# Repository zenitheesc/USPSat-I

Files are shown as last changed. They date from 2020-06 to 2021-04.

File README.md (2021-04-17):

<h1 align="center" style="color:white; background-color:black">USP Sat-I</h1>
<h4 align="center">This is an Open Hardware and Software cubesat developed by Zenith EESC-USP for the Cubedesign 2019.</h4>

<p align="center">
	<a href="http://zenith.eesc.usp.br/">
    
    </a>
    <a href="https://eesc.usp.br/">
    
    </a>
    <a href="https://github.com/zenitheesc/USPSat-AE1/blob/main/LICENSE">
    
    </a>
    <a href="https://github.com/zenitheesc/USPSat-AE1/issues">
    
    </a>
    <a href="https://github.com/zenitheesc/USPSat-AE1/commits/main">
    
    </a>
    <a href="https://github.com/zenitheesc/USPSat-AE1/graphs/contributors">
    
    </a>
    <a href="https://github.com/zenitheesc/USPSat-AE1/commits/main">
    
    </a>
    <a href="https://github.com/zenitheesc/USPSat-AE1/issues">
    
    </a>
    <a href="https://github.com/zenitheesc/USPSat-AE1/pulls">
    
    </a>
</p>

This project was based on a distributed processing architecture and it uses microcontrollers with ARM architecture. The Embedded System is composed by six subsystems:

<a href="https://github.com/zenitheesc/USPSat-AE1/tree/master/M%C3%B3dulo_Ribatski%20v.1.0"><h2>1. Thermal management</h2></a>

<p align = "center">

</p>

This subsystem is primarily responsible for
the active thermal control of the batteries, as proposed by the competition,
in addition to supporting the deployment system of the nanosatellite antennas.

<a href="https://github.com/zenitheesc/USPSat-AE1/tree/master/Varela-Logical_EPS%20v.1.0"><h2>2. Logical EPS</h2></a>
<p align = "center">

</p>

Ensures the monitoring and control of EPS panel parameters,
that is, it performs the measurement of voltage and current levels at various points on the CubeSat;
monitors the temperature of the batteries and acts to keep it always positive, in addition to
carrying out the communication to other subsystems.

<a href="https://github.com/zenitheesc/USPSat-AE1/tree/master/London-Power_EPS%20v.1.1"><h2>3. Power EPS</h2></a>

<p align = "center">

</p>

Functioning as an extension of the previous subsystem, it performs conversions of battery voltage levels to the levels requested within the
hardware, making the necessary distribution, as well as controlling the loading of batteries through solar panels.

<a href="https://github.com/zenitheesc/USPSat-AE1/tree/master/Caurin_CDH%20v.1.0"><h2>4. Comanding and Data Handling</h2></a>

<p align = "center">

</p>

It concentrates one of the processing within CubeSat. It is responsible for managing the information
present in the prototype's internal network, by managing the information received and sent to the Control Base and control of the deployment of the antennas.

<a href="https://github.com/zenitheesc/USPSat-AE1/tree/master/Comin_CTR%20v.1.0"><h2>5. Computer Vision</h2></a>

<p align = "center">

</p>
This subsystem is responsible for image aquisition and on board image processing, for attitude determination using computer vision.

<a href="https://github.com/zenitheesc/USPSat-AE1/tree/master/Alves_ADC%20v.1.0"><h2> 6. Attitude Control </h2></a>

<p align = "center">

</p>

The entire stabilization and pointing system must be done necessary to fulfill the competition missions. For this, the reading is done necessary sensors, activating a reaction wheel, which, by means of the Law of
Conservation of Angular Momentum, manages to act in the attitude of the satellite.

## 7. Structures

<p align = "center">

</p>

Finally, we have the subsystem responsible for the physical integration of all
the subsystems described earlier. All manufacturing issues involving
the physical structure of USPSat is the responsibility of the structures subsystem. The
determination of the materials used, the choice of manufacturing processes and display of all components, aiming at a satisfactory performance in the
vibration, are the main focuses of this subsystem

## Official Documentation

Check out the official documentation [here](https://github.com/zenitheesc/USPSat-AE1/blob/master/USPSat_Report.pdf).

<p align = "center">



</p>

<p align="center">
    <a href="http://zenith.eesc.usp.br">
    
    </a> 
    <a href="https://www.facebook.com/zenitheesc">
    
    </a> 
    <a href="https://www.instagram.com/zenith_eesc/">
    
    </a>

</p>
<p align = "center">
<a href="zenith.eesc@gmail.com">zenith.eesc@gmail.com</a>
</p>

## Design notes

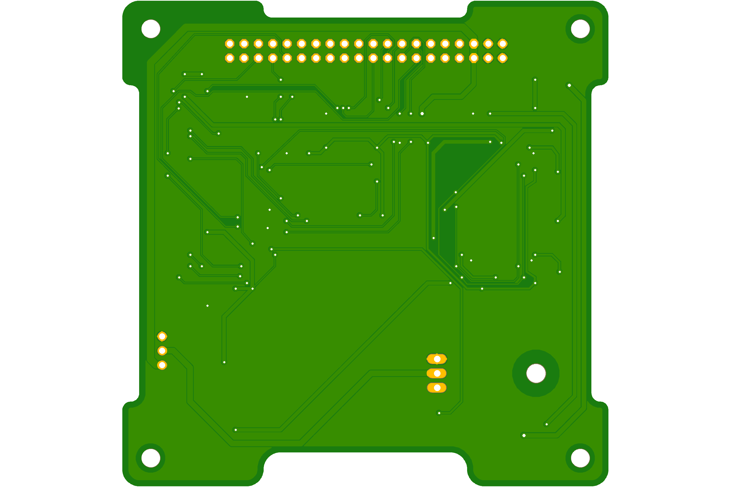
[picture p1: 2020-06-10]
Varela-Logical_EPS v.1.0/Images/Varela-Logical_EPS v.1.0 - Bottom.png

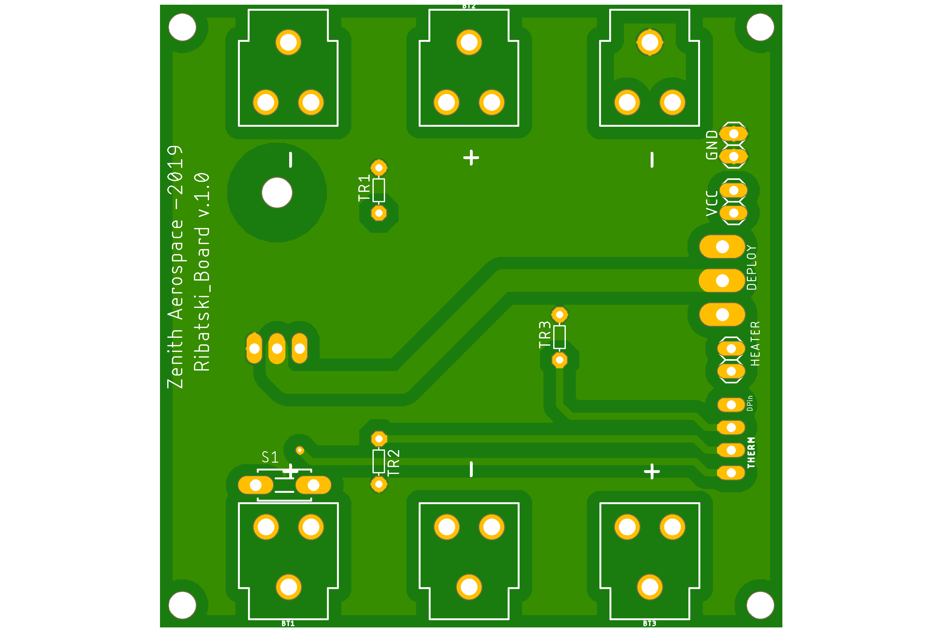
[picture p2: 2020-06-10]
Módulo_Ribatski v.1.0/Images/Módulo_Ribatski v.1.0 - Top.png

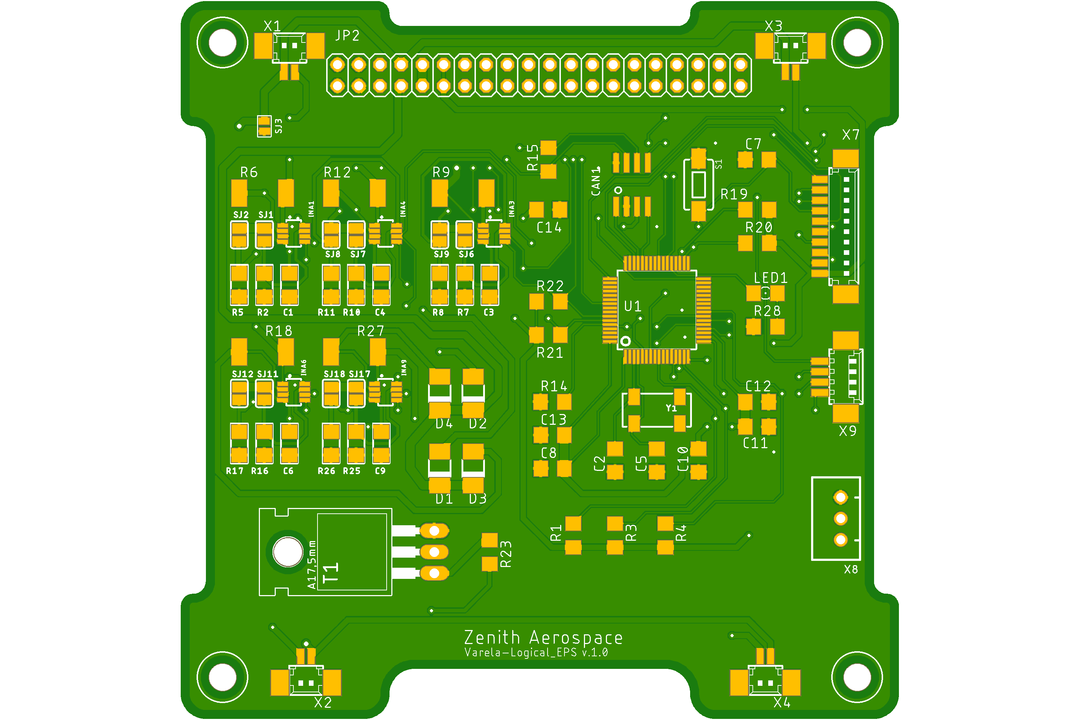
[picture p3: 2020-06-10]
Varela-Logical_EPS v.1.0/Images/Varela-Logical_EPS v.1.0 - Top.png

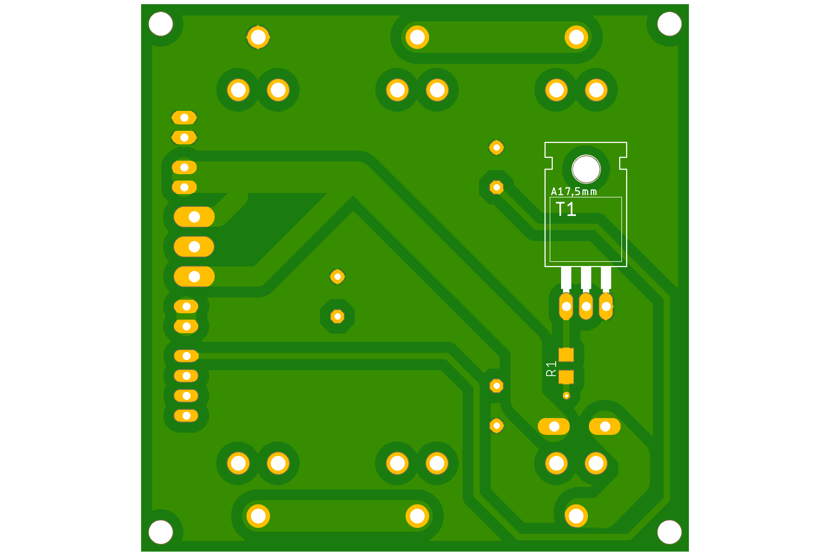
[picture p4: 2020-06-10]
Módulo_Ribatski v.1.0/Images/Módulo_Ribatski v.1.0 - Bottom.png

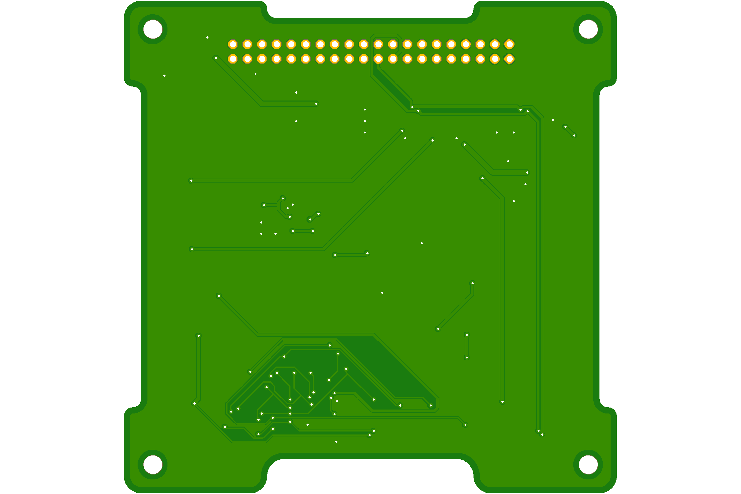
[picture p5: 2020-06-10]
London-Power_EPS v.1.1/Images/London-Power_EPS v.1.1 - Bottom.png

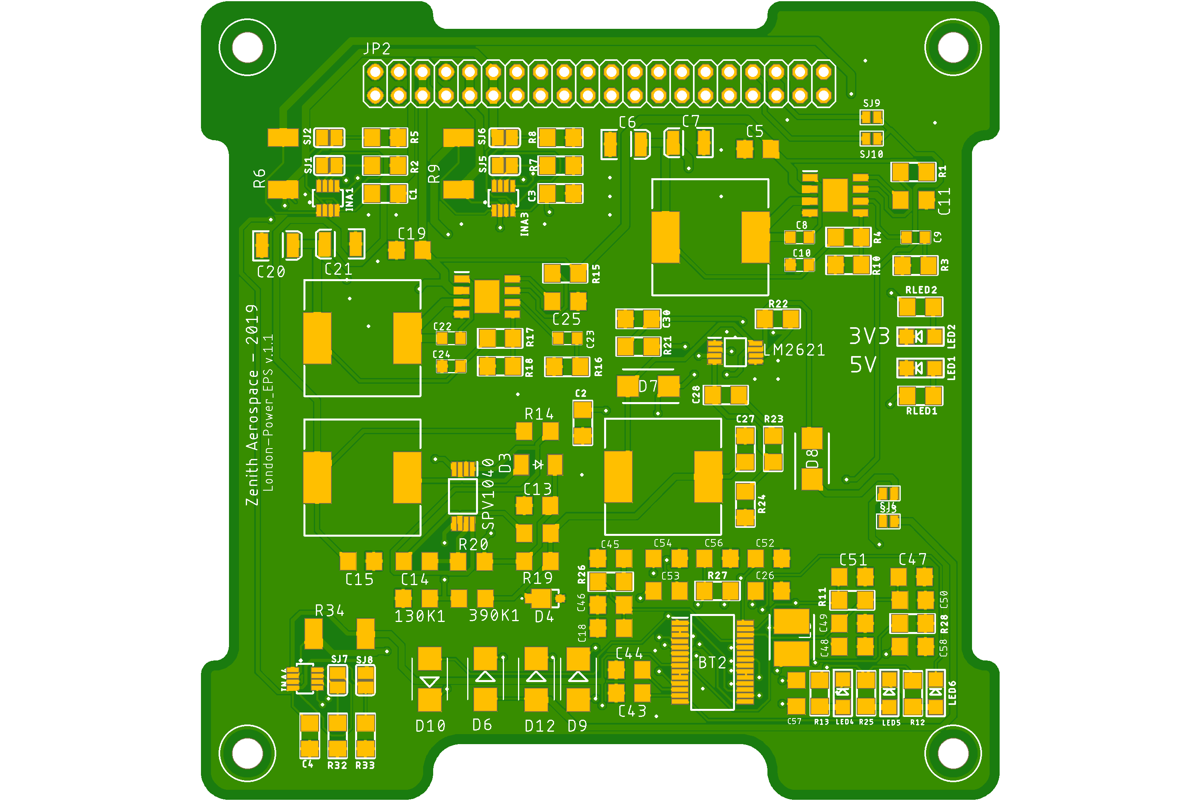
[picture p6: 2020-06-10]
London-Power_EPS v.1.1/Images/London-Power_EPS v.1.1 - Top.png

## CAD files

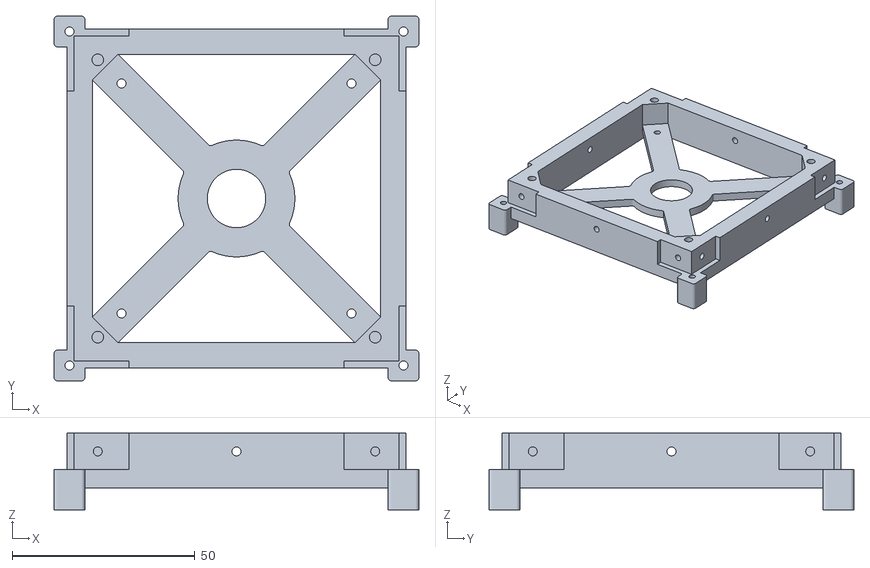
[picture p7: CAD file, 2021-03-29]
Estruturas/Base stl.stl
100.0 x 100.0 x 21.0

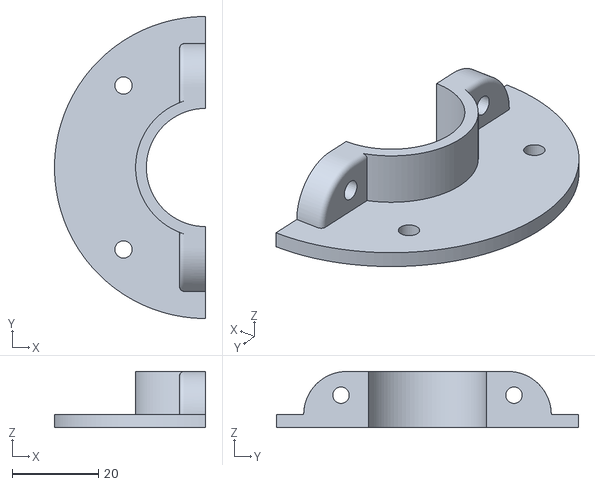
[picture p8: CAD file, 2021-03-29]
Estruturas/Espaçadores e Suporte motor/Suporte motor .stl
35.0 x 70.0 x 13.0

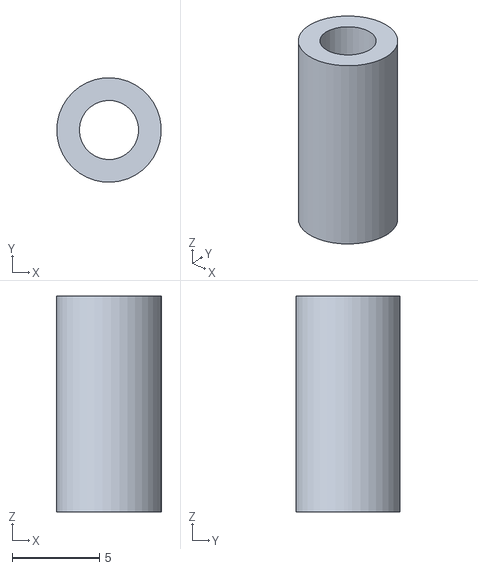
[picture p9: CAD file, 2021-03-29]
Estruturas/Espaçadores e Suporte motor/Espaçador_Placas.stl
6.00 x 6.00 x 12.4

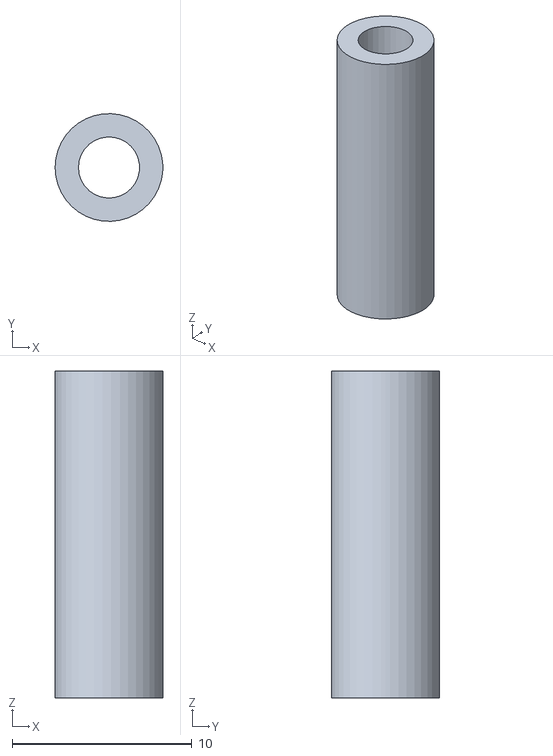
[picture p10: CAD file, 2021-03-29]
Estruturas/Espaçadores e Suporte motor/Espaçador_Base_Motor.stl
6.00 x 6.00 x 18.2

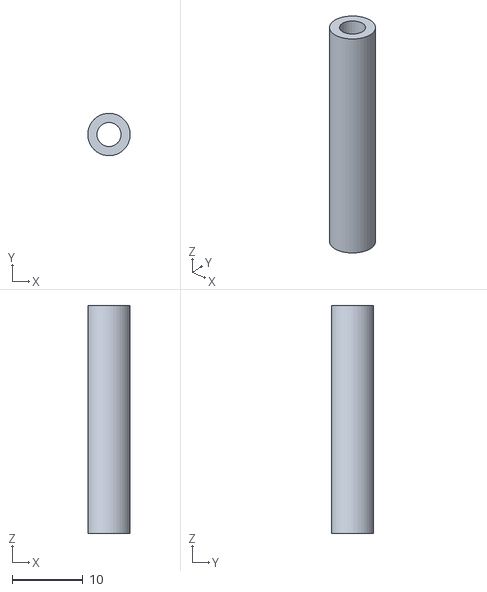
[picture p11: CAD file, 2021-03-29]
Estruturas/Espaçadores e Suporte motor/Espaçador_Meio.stl
6.00 x 6.00 x 32.2

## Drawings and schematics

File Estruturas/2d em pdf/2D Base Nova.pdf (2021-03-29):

B
C

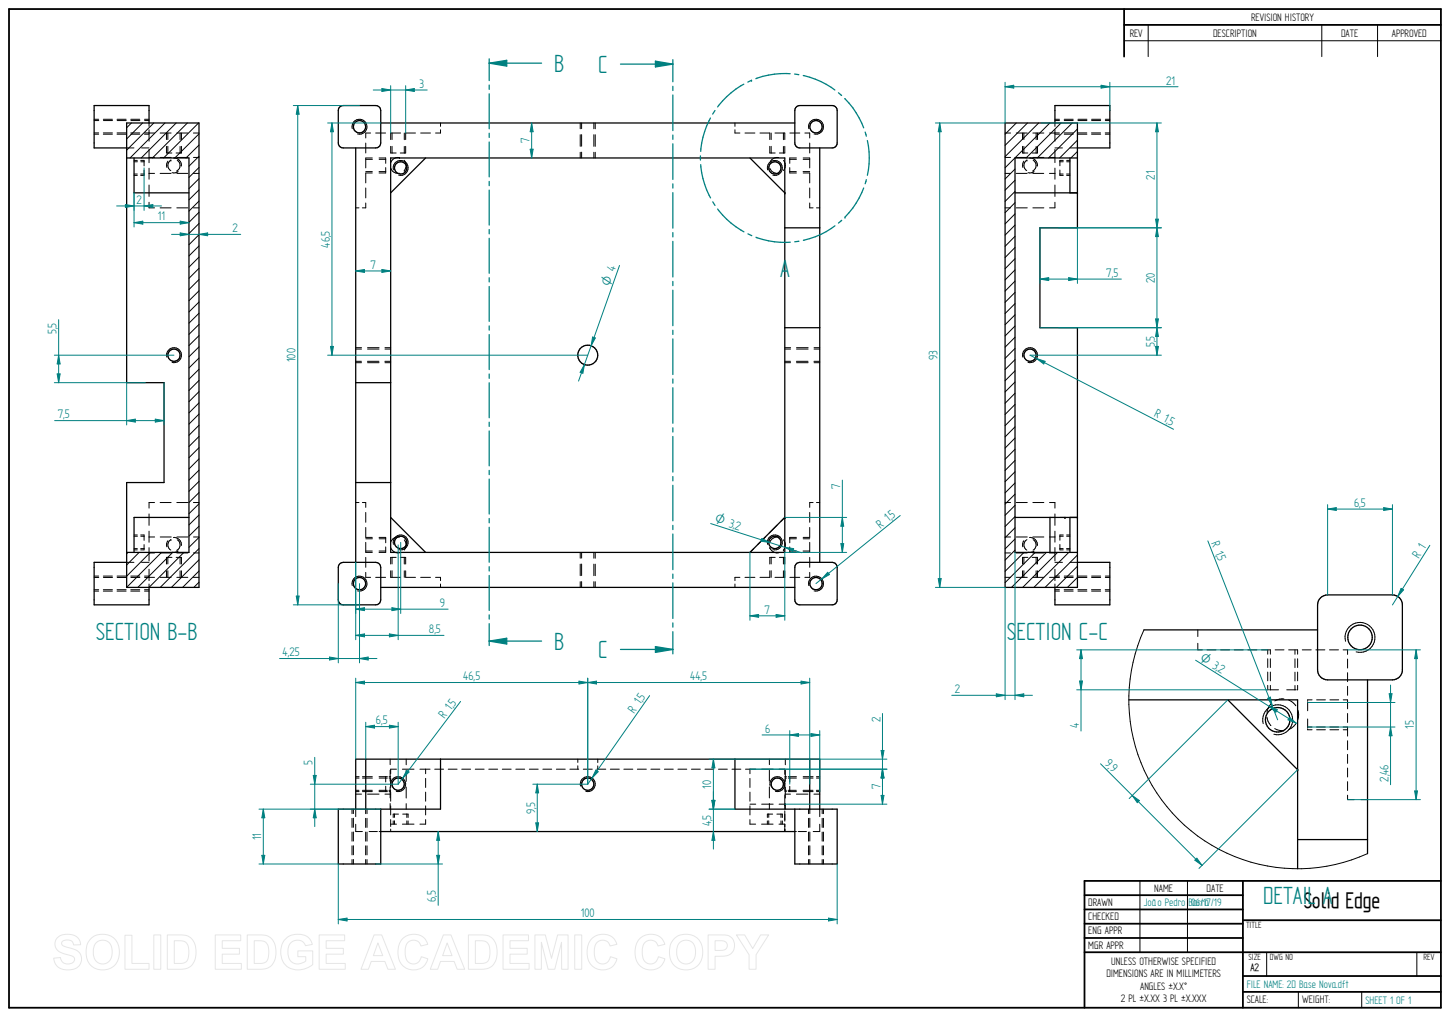
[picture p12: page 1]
TITLE; SCALE:; WEIGHT:; SHEET 1 OF 1; B SECTION B-B; SECTION C-C

REVISION HISTORY

REV | DESCRIPTION | DATE | APPROVED

NAME | DATE | DETAIL A Solid Edge

DRAWN | João Pedro Barra | 06/17/19

CHECKED
ENG APPR
MGR APPR
UNLESS OTHERWISE SPECIFIED DIMENSIONS ARE IN MILLIMETERS ANGLES ±X.X° 2 PL ±X.XX 3 PL ±X.XXX | SIZE A2 | DWG NO | REV

FILE NAME: 2D Base Nova.dft

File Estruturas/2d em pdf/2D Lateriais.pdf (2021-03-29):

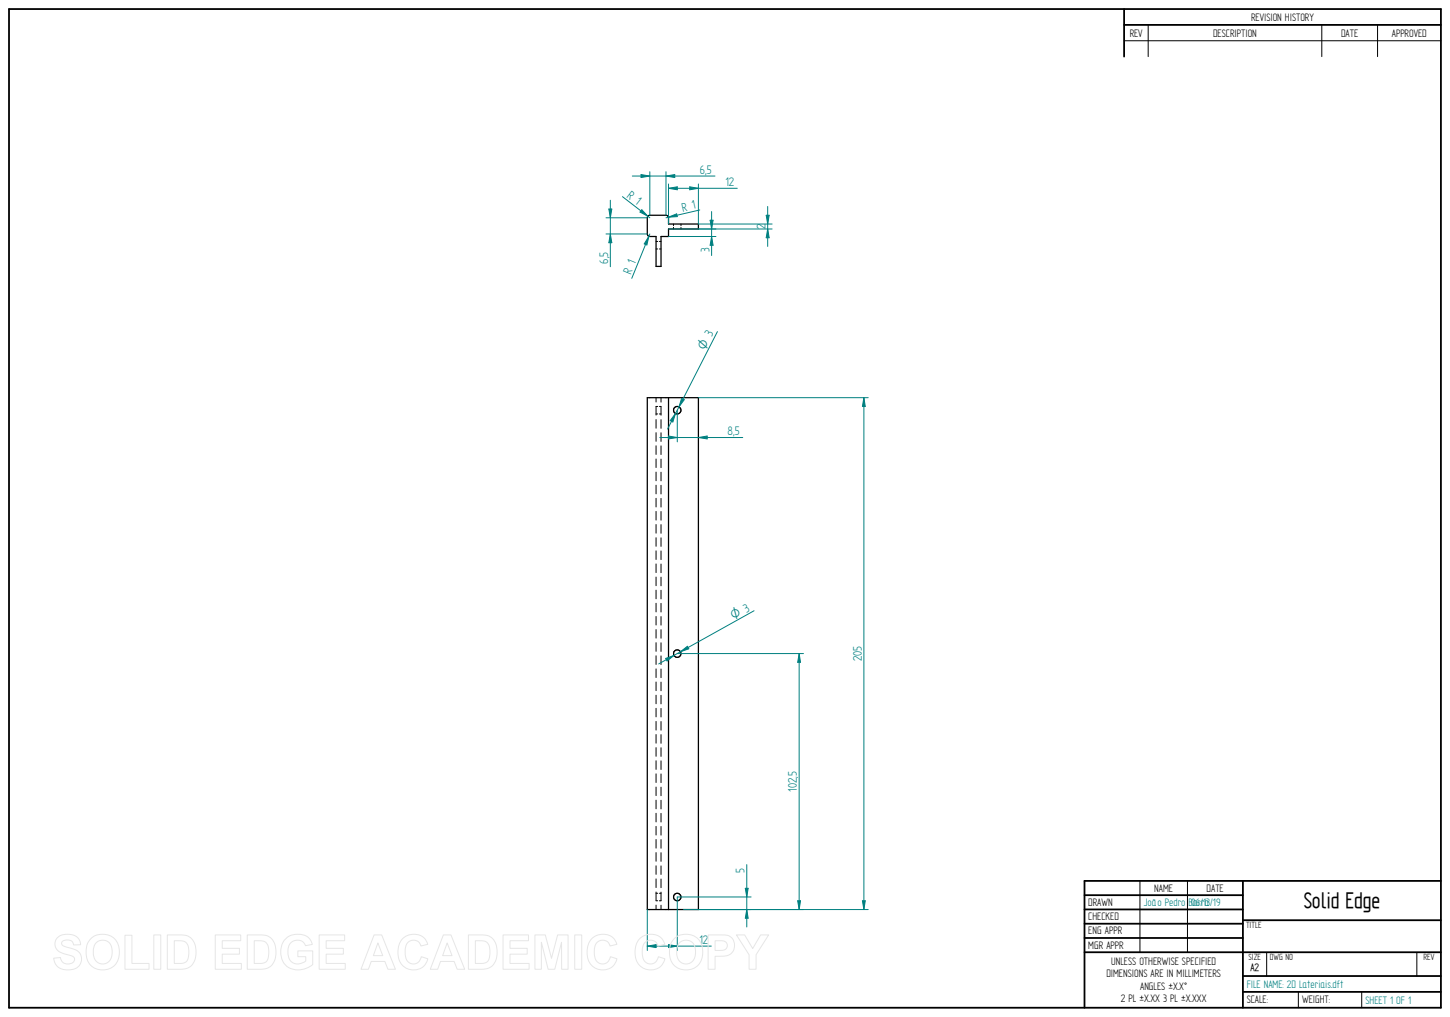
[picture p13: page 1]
TITLE; SCALE:; WEIGHT:; SHEET 1 OF 1

REVISION HISTORY

REV | DESCRIPTION | DATE | APPROVED

NAME | DATE | Solid Edge

DRAWN | João Pedro Barra | 06/13/19

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

FILE NAME: 2D Lateriais.dft

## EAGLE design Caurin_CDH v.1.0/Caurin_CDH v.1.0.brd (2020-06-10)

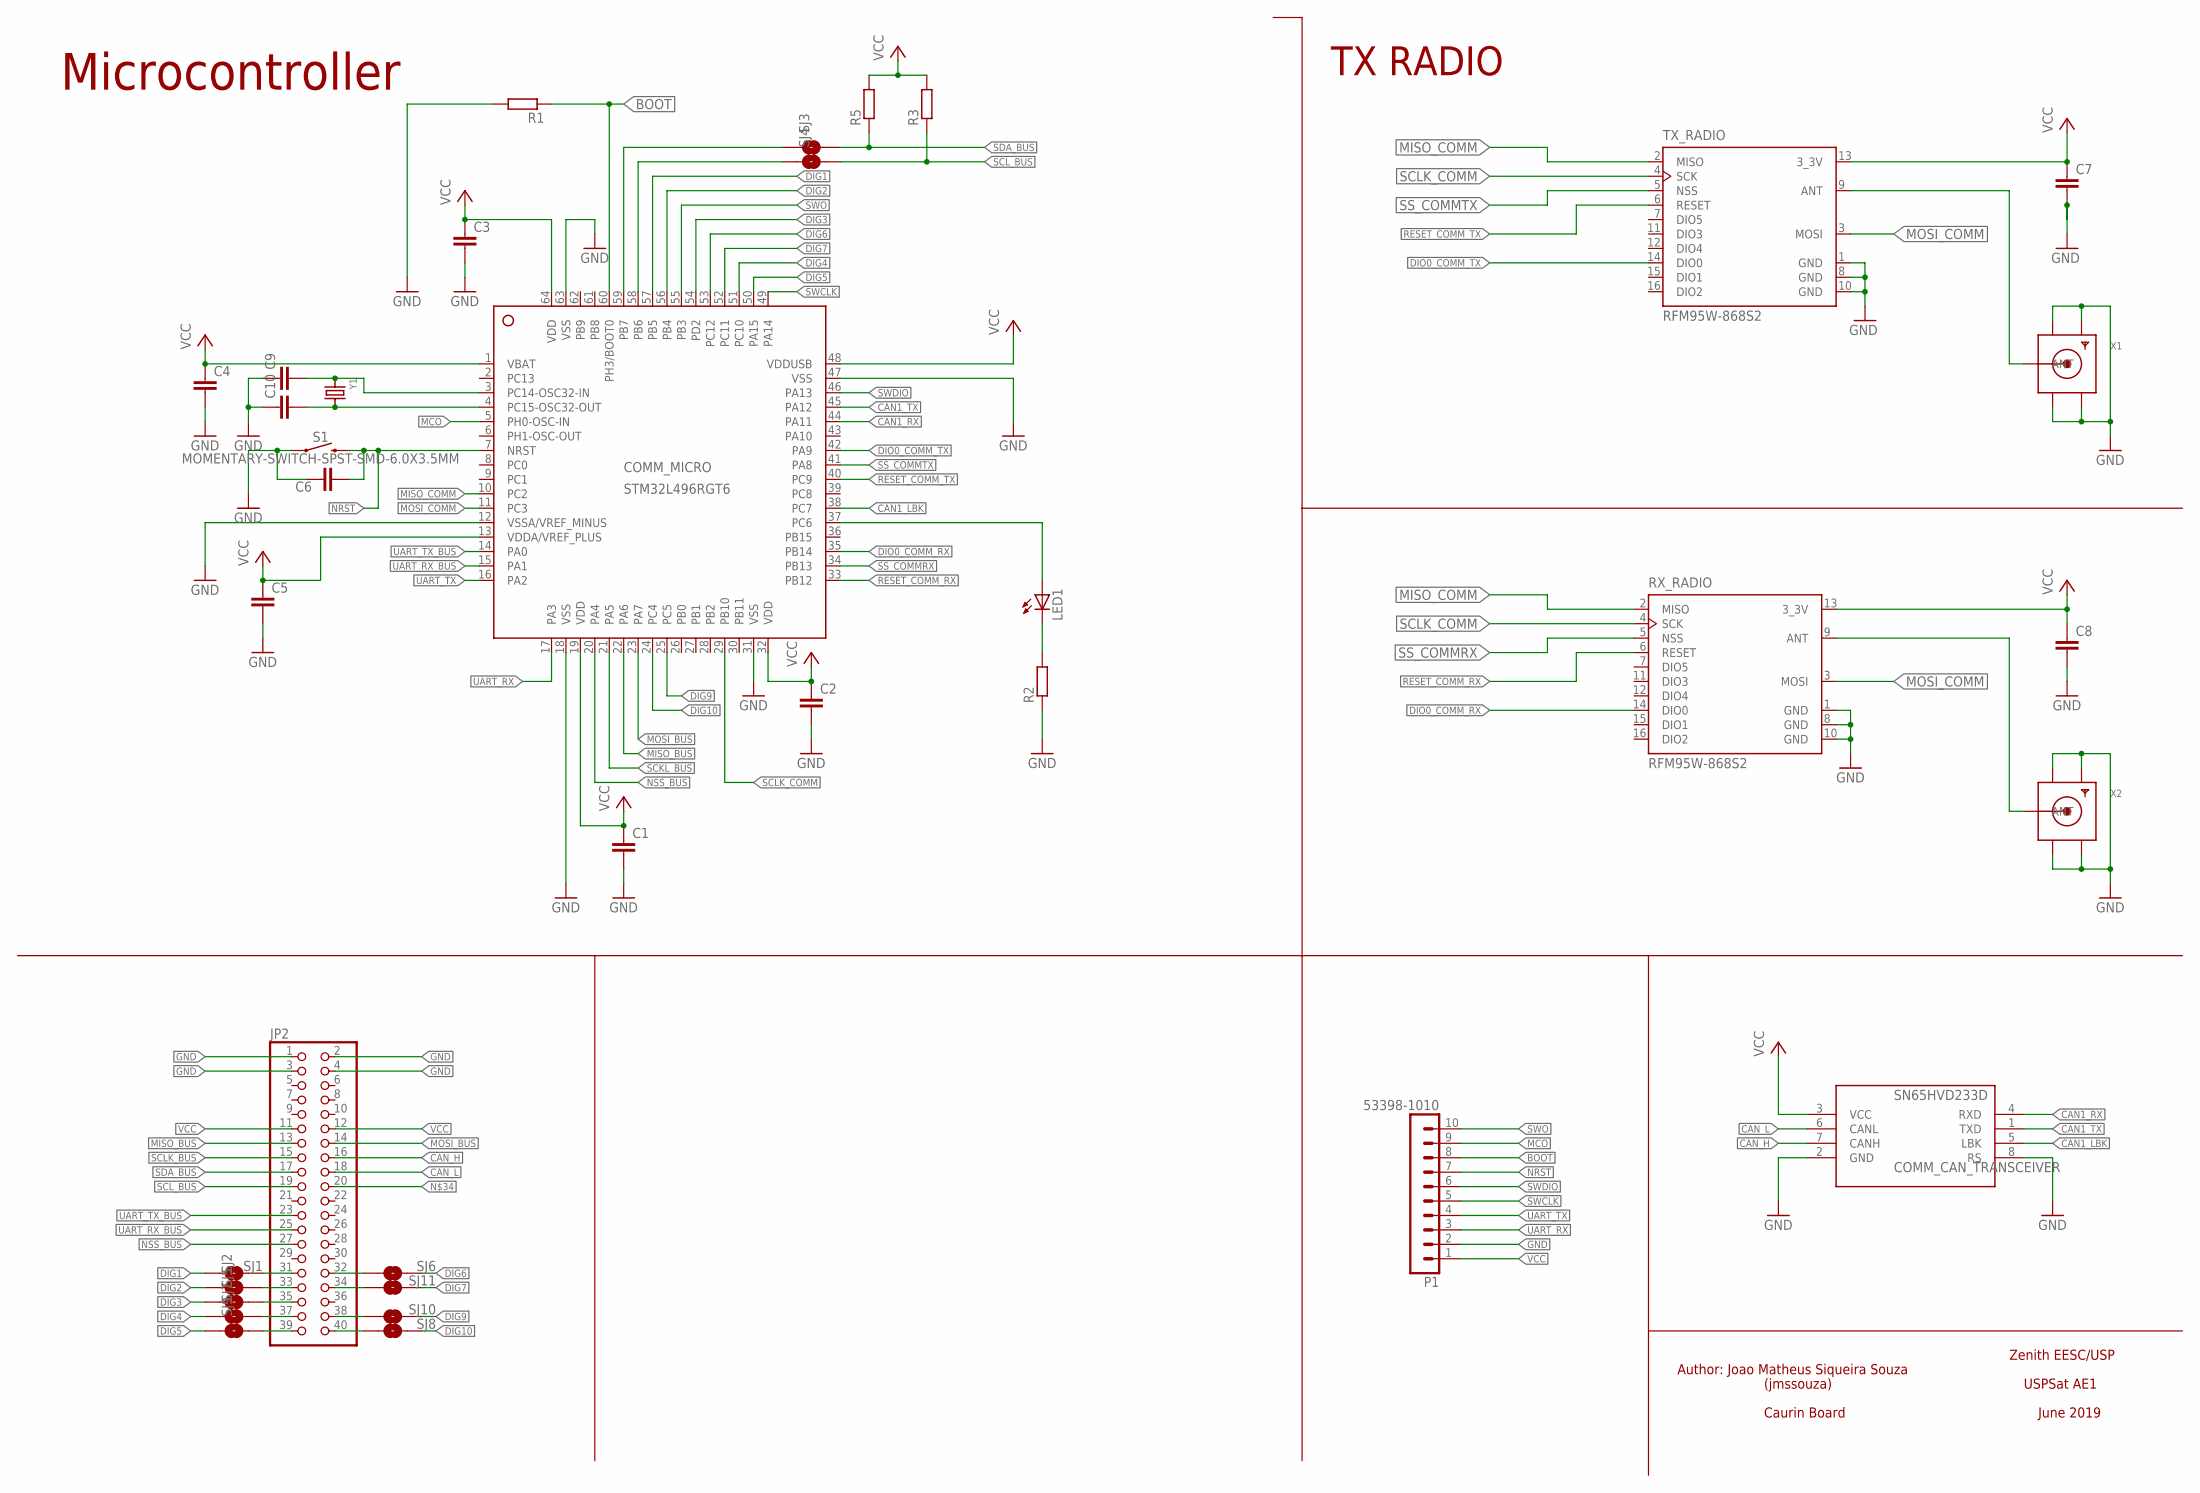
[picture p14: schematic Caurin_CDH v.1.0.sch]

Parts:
C1, C2, C3, C4, C5, C6, C7, C8, C9, C10: CC1206; C1206
COMM_CAN_TRANSCEIVER: SN65HVD233D; SOIC8
COMM_MICRO: STM32L496RGT6; LQFP64_10X10
JP2: PINHD-2X20; 2X20
LED1: LED_E; LED_1206
P1: 53398-1010
R1, R2, R3, R5: RR1206; R1206
RX_RADIO: RFM95W-868S2; XCVR_RFM95W-868S2
S1: MOMENTARY-SWITCH-SPST-SMD-6.0X3.5MM; TACTILE_SWITCH_SMD_6.0X3.5MM
SJ1, SJ2, SJ3, SJ4, SJ5, SJ6, SJ7, SJ8, SJ9, SJ10, SJ11: SMD-JUMPER-2
TX_RADIO: RFM95W-868S2; XCVR_RFM95W-868S2
X1, X2: SMACONNECTOR; SMA90_DIP
Y1: CRYSTAL8X3.8SMT; CRYSTAL_8X3.8

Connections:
BOOT: COMM_MICRO.60 (PH3/BOOT0), P1.8, R1.1
CAN1_LBK: COMM_CAN_TRANSCEIVER.5 (LBK), COMM_MICRO.38 (PC7)
CAN1_RX: COMM_CAN_TRANSCEIVER.4 (RXD), COMM_MICRO.44 (PA11)
CAN1_TX: COMM_CAN_TRANSCEIVER.1 (TXD), COMM_MICRO.45 (PA12)
CAN_H: COMM_CAN_TRANSCEIVER.7 (CANH), JP2.16
CAN_L: COMM_CAN_TRANSCEIVER.6 (CANL), JP2.18
DIG1: COMM_MICRO.57 (PB5), SJ1.1
DIG2: COMM_MICRO.56 (PB4), SJ2.1
DIG3: COMM_MICRO.54 (PD2), SJ5.1
DIG4: COMM_MICRO.51 (PC10), SJ7.1
DIG5: COMM_MICRO.50 (PA15), SJ9.1
DIG6: COMM_MICRO.53 (PC12), SJ6.2
DIG7: COMM_MICRO.52 (PC11), SJ11.2
DIG9: COMM_MICRO.25 (PC5), SJ10.2
DIG10: COMM_MICRO.24 (PC4), SJ8.2
DIO0_COMM_RX: COMM_MICRO.35 (PB14), RX_RADIO.14 (DIO0)
DIO0_COMM_TX: COMM_MICRO.42 (PA9), TX_RADIO.14 (DIO0)
GND: C1.2, C2.2, C3.2, C4.2, C5.2, C6.1, C7.2, C8.2, C9.1, C10.1, COMM_CAN_TRANSCEIVER.2 (GND), COMM_CAN_TRANSCEIVER.8 (RS), COMM_MICRO.12 (VSSA/VREF_MINUS), COMM_MICRO.18 (VSS), COMM_MICRO.31 (VSS), COMM_MICRO.47 (VSS), COMM_MICRO.63 (VSS), JP2.1, JP2.2, JP2.3, JP2.4, P1.2, R1.2, R2.1, RX_RADIO.1 (GND), RX_RADIO.8 (GND), RX_RADIO.10 (GND), S1.1, TX_RADIO.1 (GND), TX_RADIO.8 (GND), TX_RADIO.10 (GND), X1.GND1, X1.GND2, X1.GND3, X1.GND4, X2.GND1, X2.GND2, X2.GND3, X2.GND4
MCO: COMM_MICRO.5 (PH0-OSC-IN), P1.9
MISO_BUS: COMM_MICRO.22 (PA6), JP2.13
MISO_COMM: COMM_MICRO.10 (PC2), RX_RADIO.2 (MISO), TX_RADIO.2 (MISO)
MOSI_BUS: COMM_MICRO.23 (PA7), JP2.14
MOSI_COMM: COMM_MICRO.11 (PC3), RX_RADIO.3 (MOSI), TX_RADIO.3 (MOSI)
unnamed: RX_RADIO.9 (ANT), X2.ANTENNA (ANT)
unnamed: COMM_MICRO.37 (PC6), LED1.A
unnamed: LED1.C, R2.2
unnamed: C9.2, COMM_MICRO.3 (PC14-OSC32-IN), Y1.P$1 (1)
unnamed: C10.2, COMM_MICRO.4 (PC15-OSC32-OUT), Y1.P$4 (2)
unnamed: TX_RADIO.9 (ANT), X1.ANTENNA (ANT)
unnamed: JP2.32, SJ6.1
unnamed: COMM_MICRO.59 (PB7), SJ3.1
unnamed: COMM_MICRO.58 (PB6), SJ4.1
unnamed: JP2.34, SJ11.1
unnamed: JP2.38, SJ10.1
unnamed: JP2.40, SJ8.1
unnamed: JP2.37, SJ7.2
unnamed: JP2.39, SJ9.2
unnamed: JP2.35, SJ5.2
unnamed: JP2.33, SJ2.2
unnamed: JP2.31, SJ1.2
NRST: C6.2, COMM_MICRO.7 (NRST), P1.7, S1.2
NSS_BUS: COMM_MICRO.20 (PA4), JP2.27
RESET_COMM_RX: COMM_MICRO.33 (PB12), RX_RADIO.6 (RESET)
RESET_COMM_TX: COMM_MICRO.40 (PC9), TX_RADIO.6 (RESET)
SCKL_BUS: COMM_MICRO.21 (PA5)
SCLK_BUS: JP2.15
SCLK_COMM: COMM_MICRO.29 (PB10), RX_RADIO.4 (SCK), TX_RADIO.4 (SCK)
SCL_BUS: JP2.19, R3.1, SJ4.2
SDA_BUS: JP2.17, R5.1, SJ3.2
SS_COMMRX: COMM_MICRO.34 (PB13), RX_RADIO.5 (NSS)
SS_COMMTX: COMM_MICRO.41 (PA8), TX_RADIO.5 (NSS)
SWCLK: COMM_MICRO.49 (PA14), P1.5
SWDIO: COMM_MICRO.46 (PA13), P1.6
SWO: COMM_MICRO.55 (PB3), P1.10
UART_RX: COMM_MICRO.17 (PA3), P1.3
UART_RX_BUS: COMM_MICRO.15 (PA1), JP2.25
UART_TX: COMM_MICRO.16 (PA2), P1.4
UART_TX_BUS: COMM_MICRO.14 (PA0), JP2.23
VCC: C1.1, C2.1, C3.1, C4.1, C5.1, C7.1, C8.1, COMM_CAN_TRANSCEIVER.3 (VCC), COMM_MICRO.1 (VBAT), COMM_MICRO.13 (VDDA/VREF_PLUS), COMM_MICRO.19 (VDD), COMM_MICRO.32 (VDD), COMM_MICRO.48 (VDDUSB), COMM_MICRO.64 (VDD), JP2.11, JP2.12, P1.1, R3.2, R5.2, RX_RADIO.13 (3_3V), TX_RADIO.13 (3_3V)

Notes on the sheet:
TX RADIO
Author: Joao Matheus Siqueira Souza
Zenith EESC/USP
USPSat AE1
(jmssouza)
June 2019
Caurin Board
Microcontroller

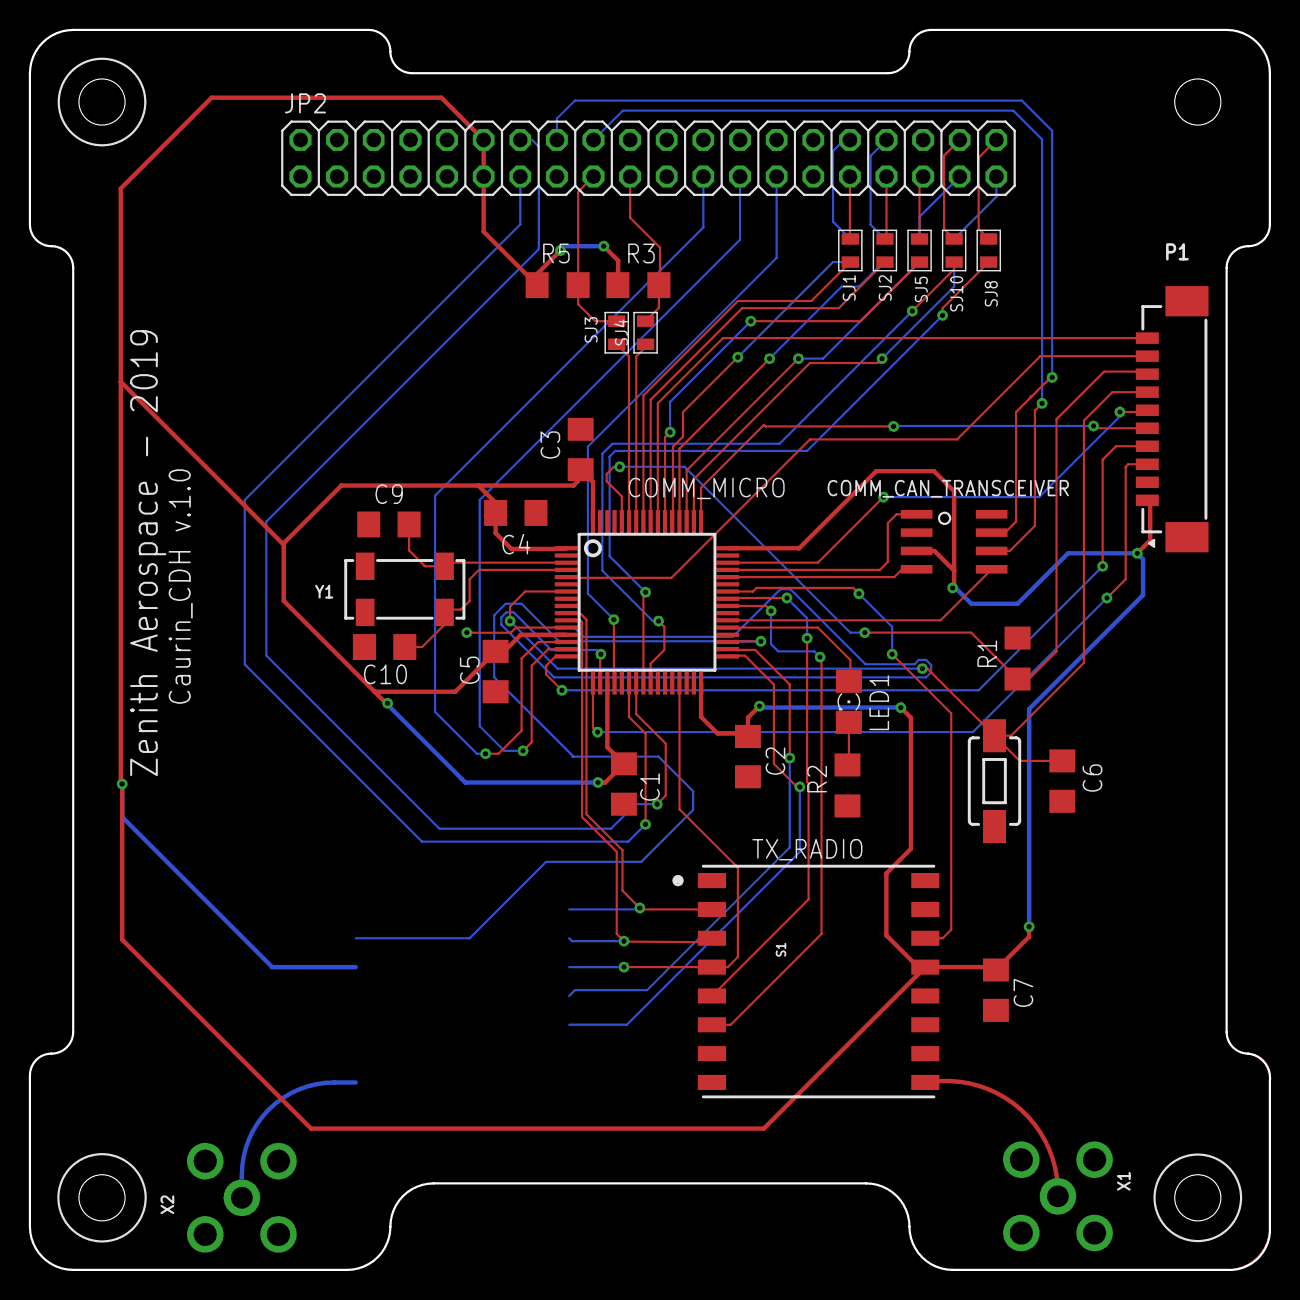
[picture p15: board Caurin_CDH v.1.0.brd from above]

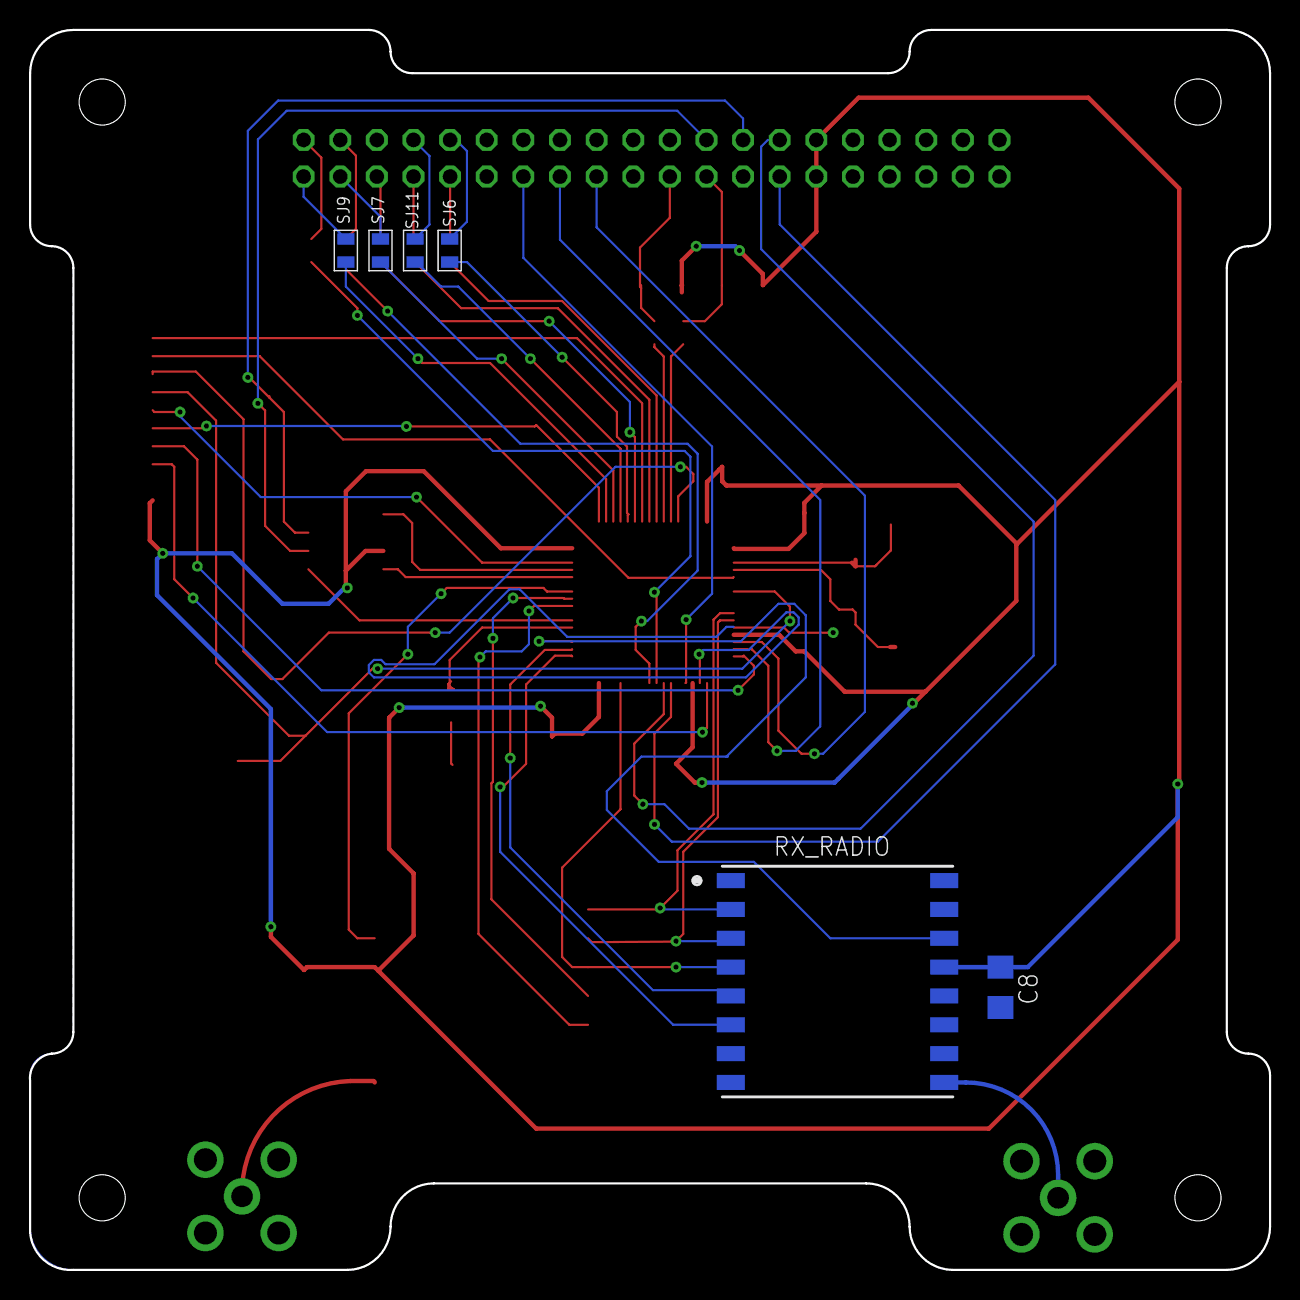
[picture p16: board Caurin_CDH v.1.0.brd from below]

Board: 2 copper layers, 86.0 x 86.0 mm, 36 parts (6 on the bottom side), 57 nets.

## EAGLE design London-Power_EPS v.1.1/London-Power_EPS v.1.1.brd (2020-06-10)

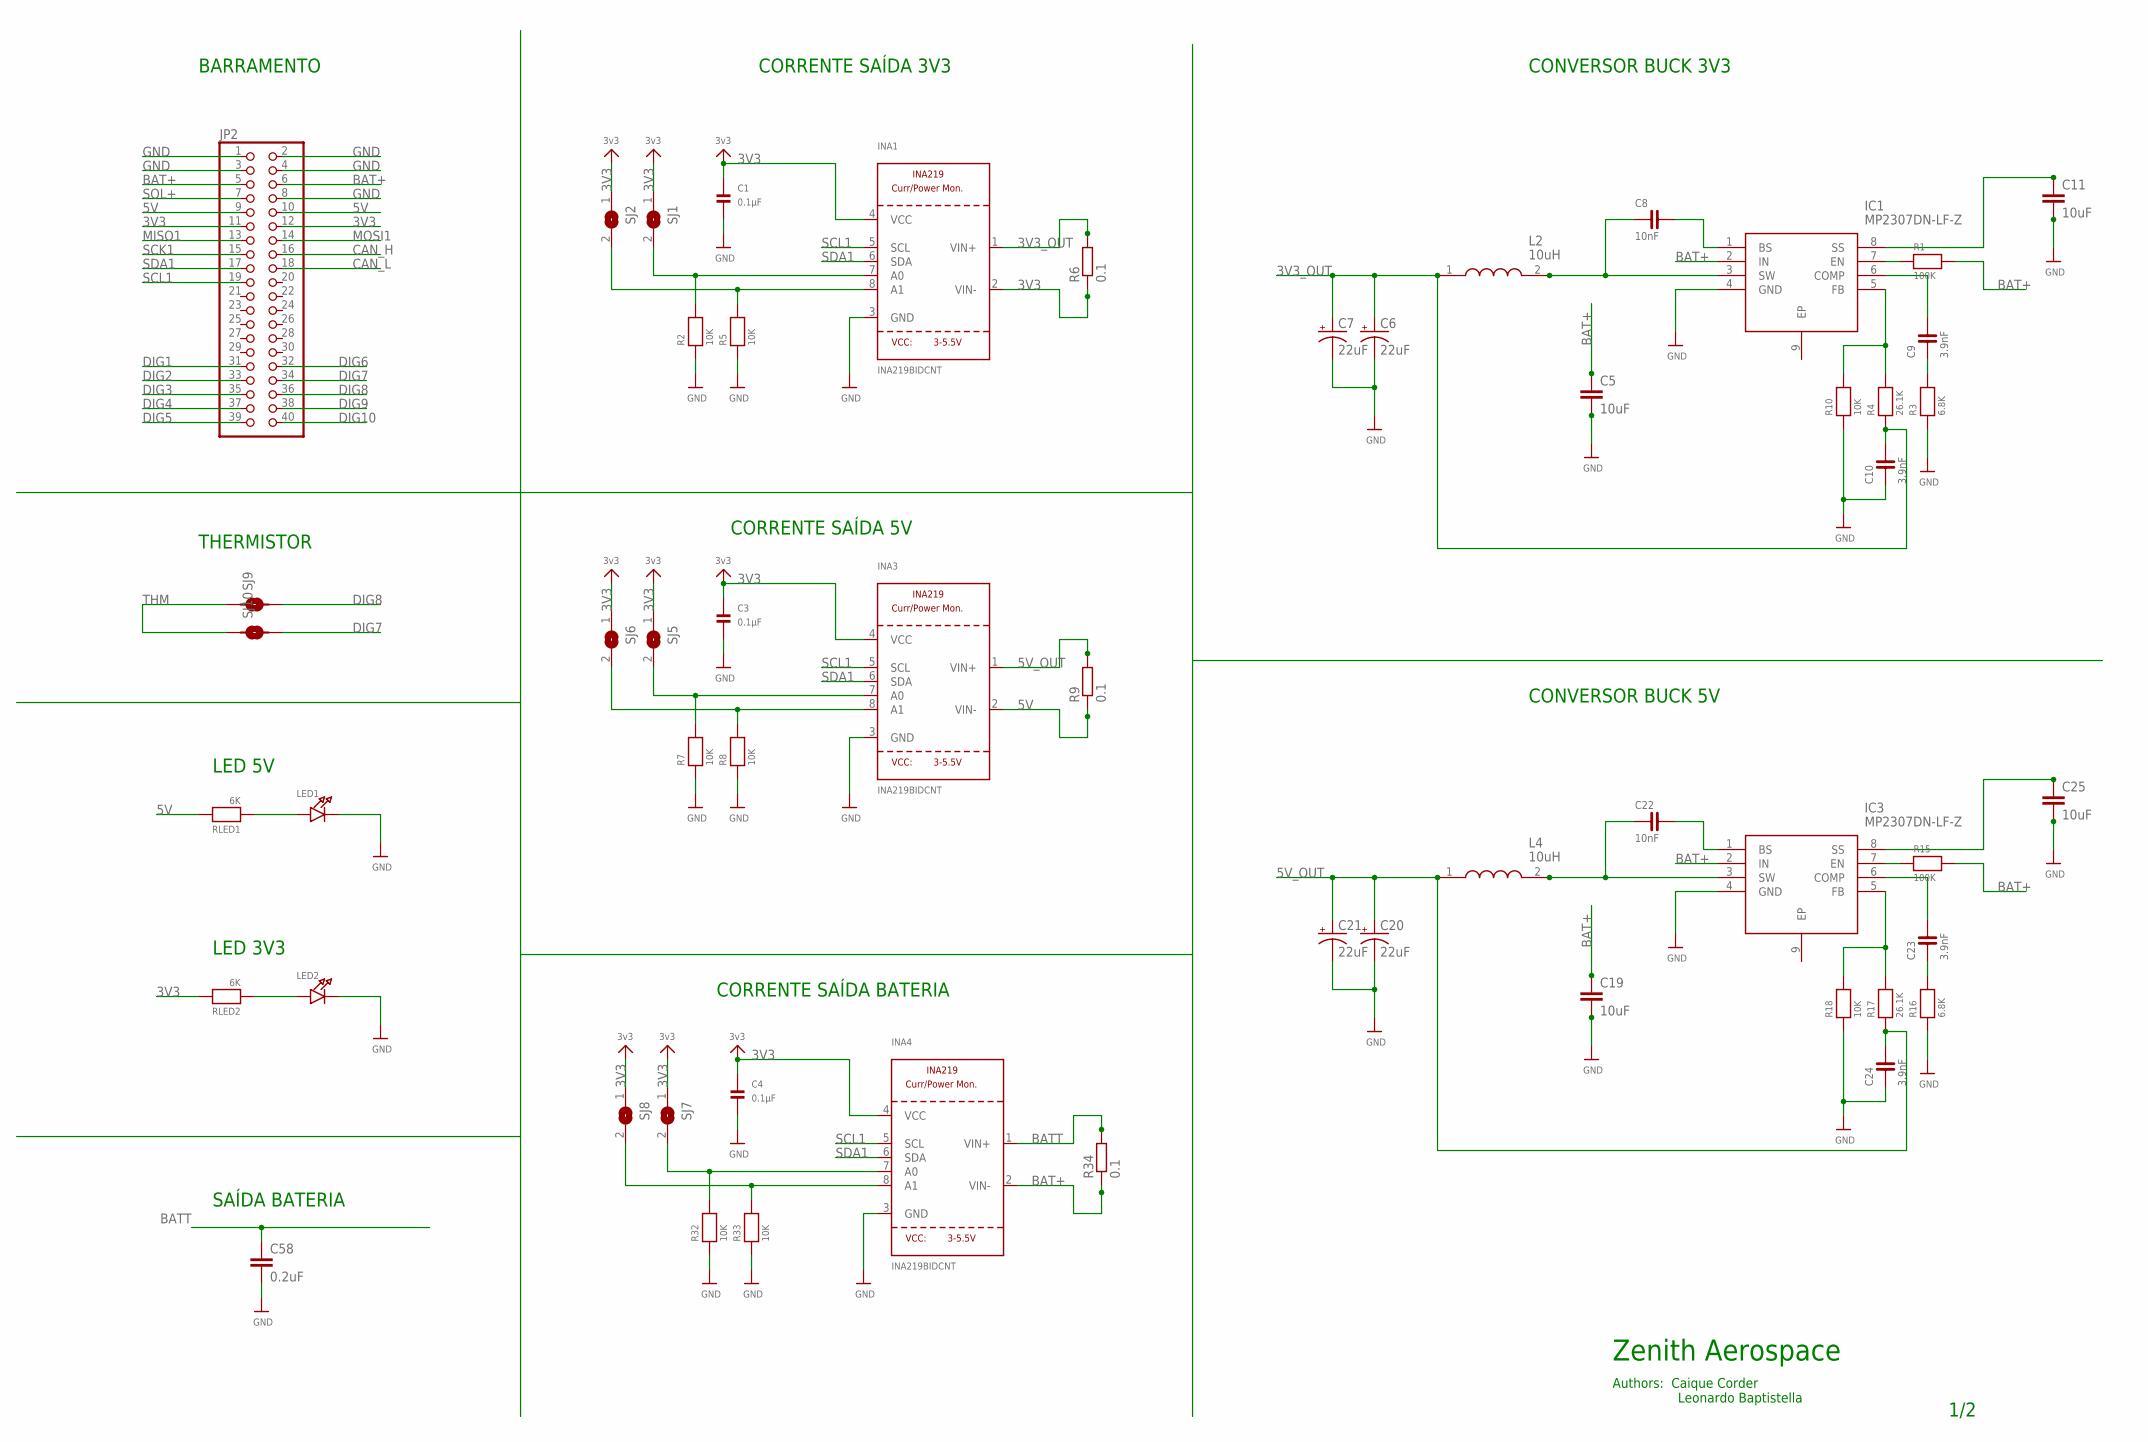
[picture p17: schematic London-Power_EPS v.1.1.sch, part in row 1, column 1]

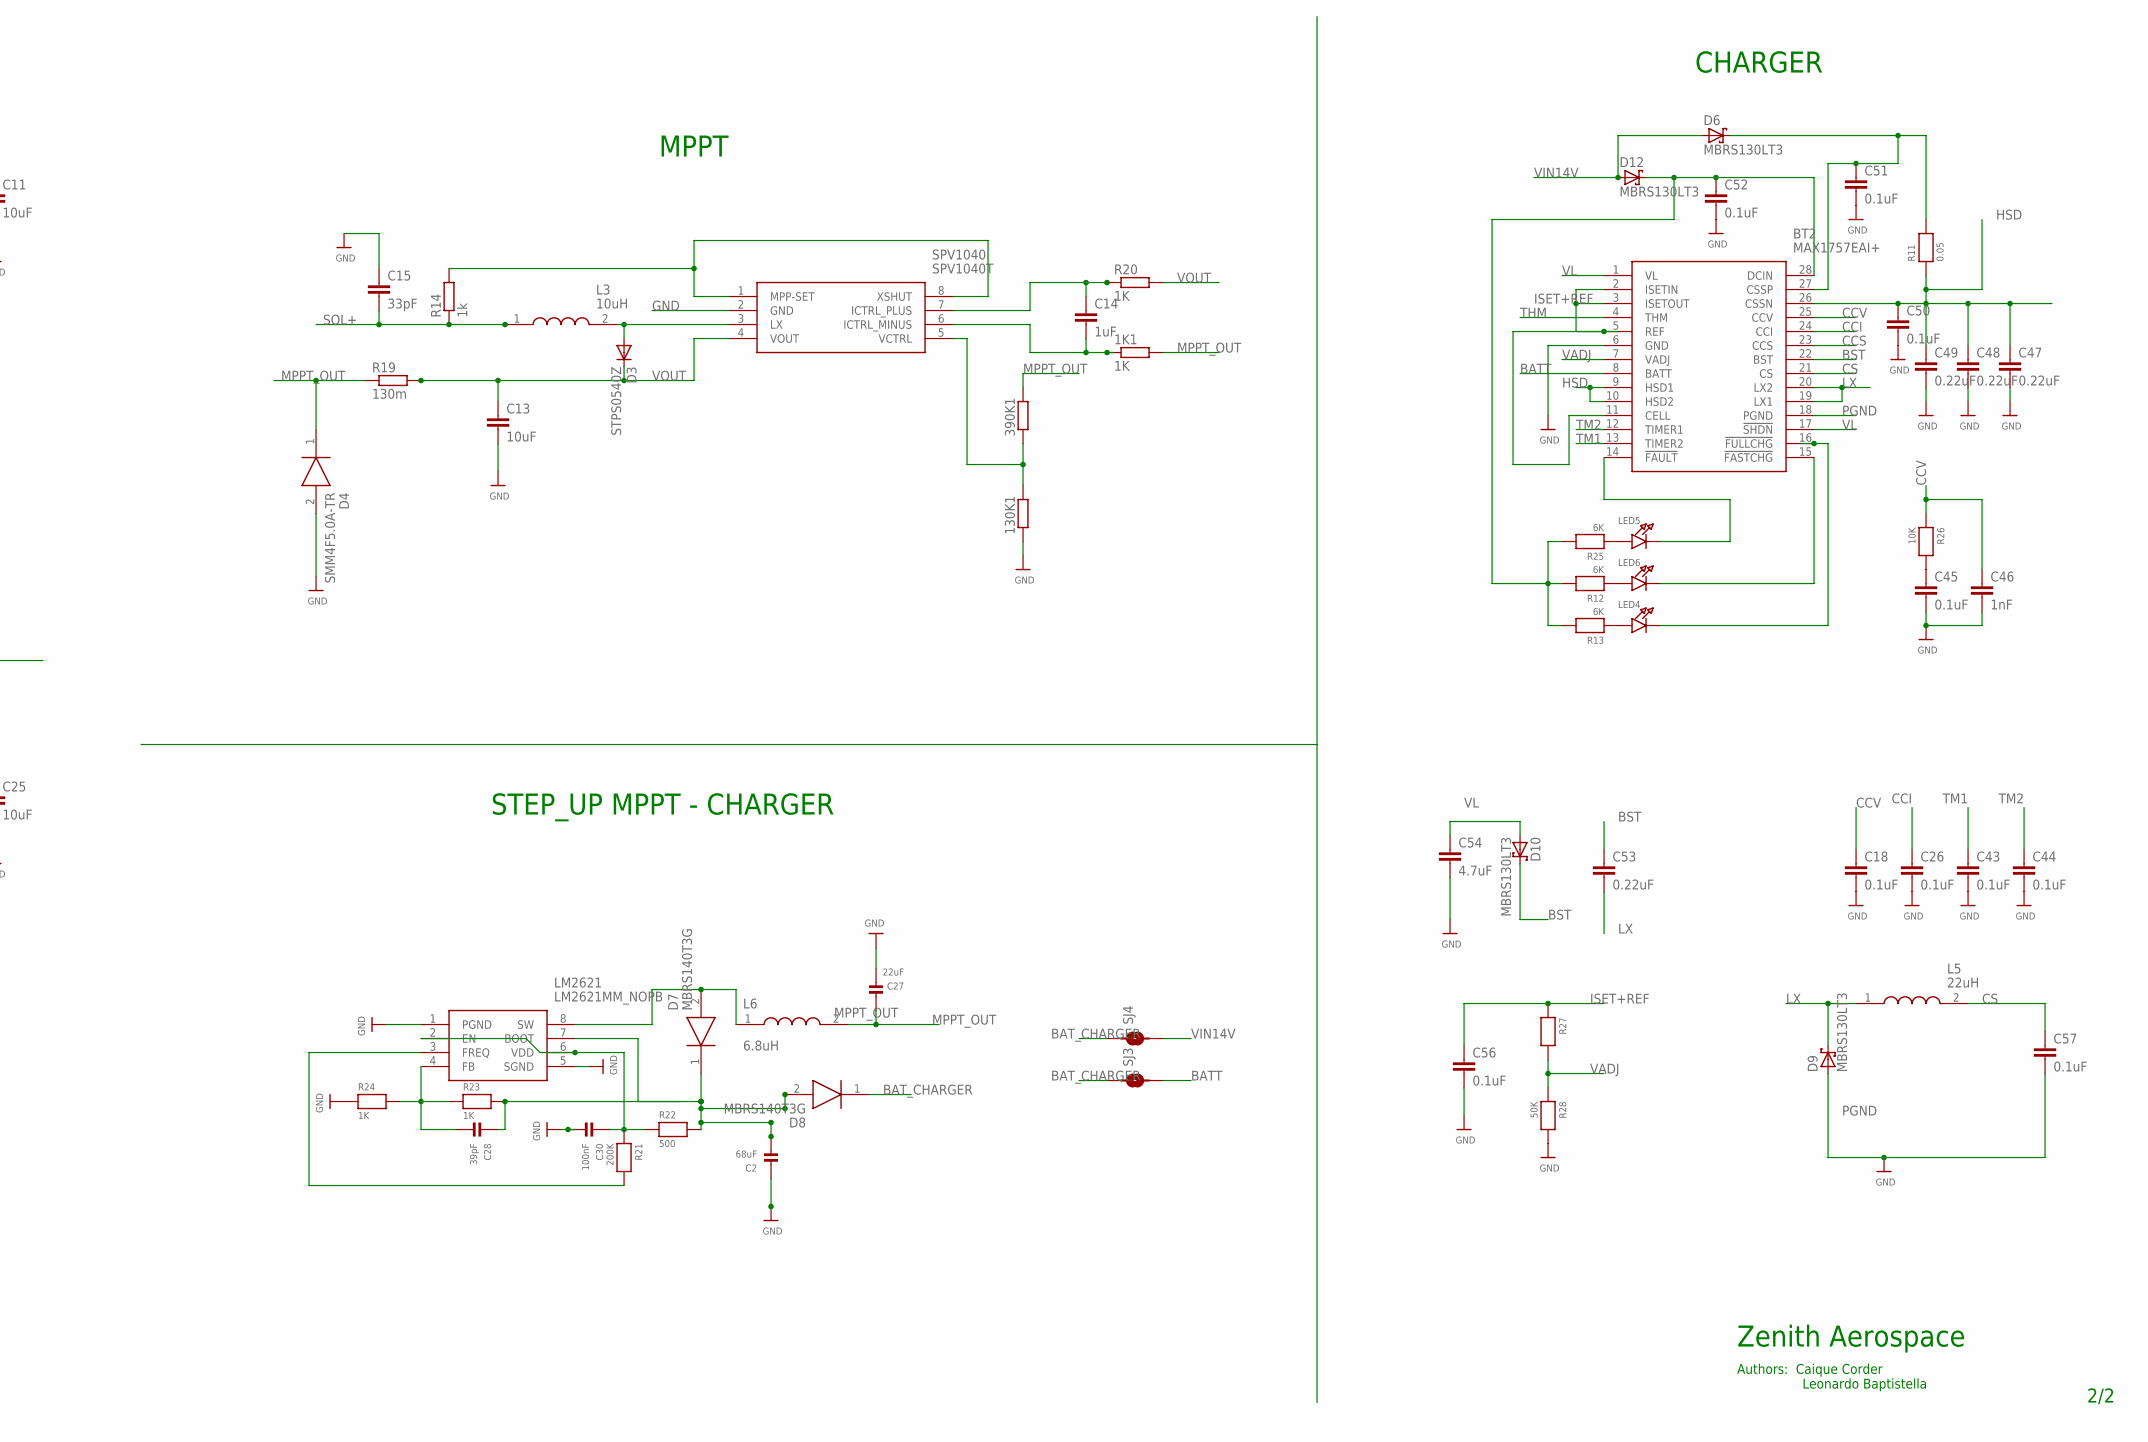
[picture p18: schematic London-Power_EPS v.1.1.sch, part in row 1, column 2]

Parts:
1K1: 1K; R1206
130K1, 390K1: RR1206; R1206
BT2: MAX1757EAI+; SOP65P778X199-28N
C1, C3, C4: 0.1µF; 1206
C2: 68uF; 1206
C5, C11, C13, C19, C25: 10uF; C1206
C6, C7, C20, C21: 22uF; EIA3528
C8, C22: 10nF; 0805
C9, C10, C23, C24: 3.9nF; 0805
C14: 1uF; C1206
C15: 33pF; C1206
C18, C26, C43, C44, C45, C50, C51, C52, C56, C57: 0.1uF; C1206
C27: 22uF; 1206
C28: 39pF; 1206
C30: 100nF; 1206
C46: 1nF; C1206
C47, C48, C49, C53: 0.22uF; C1206
C54: 4.7uF; C1206
C58: 0.2uF; C1206
D3: STPS0540Z; SOD-123_MINI-SMA
D4: SMM4F5.0A-TR; STMITE
D6, D9, D10, D12: MBRS130LT3; SMB
D7, D8: MBRS140T3G; DIOM5436X247N
IC1, IC3: MP2307DN-LF-Z; SOIC127P600X170-9N
INA1, INA3, INA4: INA219BIDCNT; SOT23-8
JP2: PINHD-2X20; 2X20
L2, L3, L4: 10uH; SRR1280-220M
L5: 22uH; INDPM4848X280N
L6: 6.8uH; SRR1280-220M
LED1, LED2, LED4, LED5, LED6: LED1206; CHIPLED_1206
LM2621: LM2621MM_NOPB; SOP65P490X110-8N
R1, R15: 100K; 1206
R2, R5, R7, R8, R10, R18, R26, R32, R33: 10K; 1206
R3, R16: 6.8K; 1206
R4, R17: 26.1K; 1206
R6, R9, R34: 0.1; R2512
R11: 0.05; 1206
R12, R13, R25: 6K; 1206
R14: 1k; R1206
R19: 130m; R1206
R20: 1K; R1206
R21: 200K; 1206
R22: 500; 1206
R23, R24: 1K; 1206
R27: RESISTOR1206; 1206
R28: 50K; 1206
RLED1, RLED2: 6K; 1206
SJ1, SJ2, SJ5, SJ6, SJ7, SJ8: SOLDERJUMPERREFLOW_NOPASTE; SOLDERJUMPER_REFLOW_NOPASTE
SJ3, SJ4, SJ9, SJ10: SMD-JUMPER-2
SPV1040: SPV1040T; SOP65P640X120-8N

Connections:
3V3: C1.1, C3.1, C4.1, INA1.2 (VIN-), INA1.4 (VCC), INA3.4 (VCC), INA4.4 (VCC), JP2.11, JP2.12, R6.1, RLED2.2, SJ1.1, SJ2.1, SJ5.1, SJ6.1, SJ7.1, SJ8.1
3V3_OUT: C6.A (+), C7.A (+), C10.2, INA1.1 (VIN+), L2.1, R4.1, R6.2
5V: INA3.2 (VIN-), JP2.9, JP2.10, R9.1, RLED1.2
5V_OUT: C20.A (+), C21.A (+), C24.2, INA3.1 (VIN+), L4.1, R9.2, R17.1
BAT+: C5.1, C19.1, IC1.2 (IN), IC3.2 (IN), INA4.2 (VIN-), JP2.5, JP2.6, R1.2, R15.2, R34.1
BATT: BT2.8 (BATT), C58.1, INA4.1 (VIN+), R34.2, SJ3.2
BAT_CHARGER: D8.1 (K), SJ3.1, SJ4.1
BST: BT2.22 (BST), C53.1, D10.C
CAN_H: JP2.16
CAN_L: JP2.18
CCI: BT2.24 (CCI), C26.1
CCS: BT2.23 (CCS)
CCV: BT2.25 (CCV), C18.1, C46.1, R26.1
CS: BT2.21 (CS), C57.1, L5.2
DIG1: JP2.31
DIG2: JP2.33
DIG3: JP2.35
DIG4: JP2.37
DIG5: JP2.39
DIG6: JP2.32
DIG7: JP2.34, SJ10.2
DIG8: JP2.36, SJ9.2
DIG9: JP2.38
DIG10: JP2.40
GND: 130K1.1, BT2.6 (GND), C1.2, C2.1, C3.2, C4.2, C5.2, C6.C (-), C7.C (-), C10.1, C11.2, C13.2, C15.1, C18.2, C19.2, C20.C (-), C21.C (-), C24.1, C25.2, C26.2, C27.2, C30.2, C43.2, C44.2, C45.2, C46.2, C47.2, C48.2, C49.2, C50.2, C51.2, C52.2, C54.2, C56.2, C58.2, D4.2 (A), IC1.4 (GND), IC3.4 (GND), INA1.3 (GND), INA3.3 (GND), INA4.3 (GND), JP2.1, JP2.2, JP2.3, JP2.4, JP2.8, LED1.C, LED2.C, LM2621.1 (PGND), LM2621.5 (SGND), R2.1, R3.1, R5.1, R7.1, R8.1, R10.1, R16.1, R18.1, R24.1, R28.2, R32.1, R33.1, SPV1040.2 (GND)
HSD: BT2.9 (HSD1), BT2.10 (HSD2), BT2.26 (CSSN), C47.1, C48.1, C49.1, C50.1, R11.1
ISET+REF: BT2.2 (ISETIN), BT2.3 (ISETOUT), BT2.5 (REF), BT2.11 (CELL), C56.1, R27.1
LX: BT2.19 (LX1), BT2.20 (LX2), C53.2, D9.C, L5.1
MISO1: JP2.13
MOSI1: JP2.14
MPPT_OUT: 1K1.2, 390K1.2, C27.1, D4.1 (K), L6.2, R19.1
unnamed: INA1.8 (A1), R5.2, SJ2.2
unnamed: INA1.7 (A0), R2.2, SJ1.2
unnamed: C8.2, IC1.1 (BS)
unnamed: C11.1, IC1.8 (SS)
unnamed: INA3.8 (A1), R8.2, SJ6.2
unnamed: INA3.7 (A0), R7.2, SJ5.2
unnamed: C8.1, IC1.3 (SW), L2.2
unnamed: IC1.7 (EN), R1.1
unnamed: C9.2, IC1.6 (COMP)
unnamed: C9.1, R3.2
unnamed: IC1.5 (FB), R4.2, R10.2
unnamed: LED2.A, RLED2.1
unnamed: LED1.A, RLED1.1
unnamed: LED6.A, R12.1
unnamed: BT2.28 (DCIN), C52.1, D12.C, R12.2, R13.2, R25.2
unnamed: BT2.14 (!FAULT), LED5.C
unnamed: D3.A, L3.2, SPV1040.3 (LX)
unnamed: R14.2, SPV1040.1 (MPP-SET), SPV1040.8 (XSHUT)
unnamed: C22.2, IC3.1 (BS)
unnamed: C25.1, IC3.8 (SS)
unnamed: C22.1, IC3.3 (SW), L4.2
unnamed: IC3.7 (EN), R15.1
unnamed: C23.2, IC3.6 (COMP)
unnamed: C23.1, R16.2
unnamed: IC3.5 (FB), R17.2, R18.2
unnamed: C14.1, R20.1, SPV1040.7 (ICTRL_PLUS)
unnamed: 1K1.1, C14.2, SPV1040.6 (ICTRL_MINUS)
unnamed: 130K1.2, 390K1.1, SPV1040.5 (VCTRL)
unnamed: BT2.15 (!FASTCHG), LED6.C
unnamed: BT2.16 (!FULLCHG), LED4.C
unnamed: INA4.8 (A1), R33.2, SJ8.2
unnamed: C2.2, D7.1 (K), D8.2 (A), LM2621.7 (BOOT), R22.2
unnamed: C30.1, LM2621.2 (EN), LM2621.6 (VDD), R21.1, R22.1
unnamed: LM2621.3 (FREQ), R21.2
unnamed: C28.2, LM2621.4 (FB), R23.1, R24.2
unnamed: C28.1, R23.2
unnamed: LED4.A, R13.1
unnamed: D7.2 (A), L6.1, LM2621.8 (SW)
unnamed: INA4.7 (A0), R32.2, SJ7.2
unnamed: LED5.A, R25.1
unnamed: C45.1, R26.2
unnamed: BT2.27 (CSSP), C51.1, D6.C, R11.2
PGND: BT2.18 (PGND), C57.2, D9.A
SCK1: JP2.15
SCL1: INA1.5 (SCL), INA3.5 (SCL), INA4.5 (SCL), JP2.19
SDA1: INA1.6 (SDA), INA3.6 (SDA), INA4.6 (SDA), JP2.17
SOL+: C15.2, JP2.7, L3.1, R14.1
THM: BT2.4 (THM), SJ9.1, SJ10.1
TM1: BT2.13 (TIMER2), C43.1
TM2: BT2.12 (TIMER1), C44.1
VADJ: BT2.7 (VADJ), R27.2, R28.1
VIN14V: D6.A, D12.A, SJ4.2
VL: BT2.1 (VL), BT2.17 (!SHDN), C54.1, D10.A
VOUT: C13.1, D3.C, R19.2, R20.2, SPV1040.4 (VOUT)

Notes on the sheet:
CORRENTE SAÍDA 3V3
CORRENTE SAÍDA 5V
CORRENTE SAÍDA BATERIA
CONVERSOR BUCK 3V3
CONVERSOR BUCK 5V
MPPT
STEP_UP MPPT - CHARGER
CHARGER
BARRAMENTO
THERMISTOR
LED 5V
LED 3V3
SAÍDA BATERIA
Zenith Aerospace
Authors: Caique Corder Leonardo Baptistella
1/2
2/2

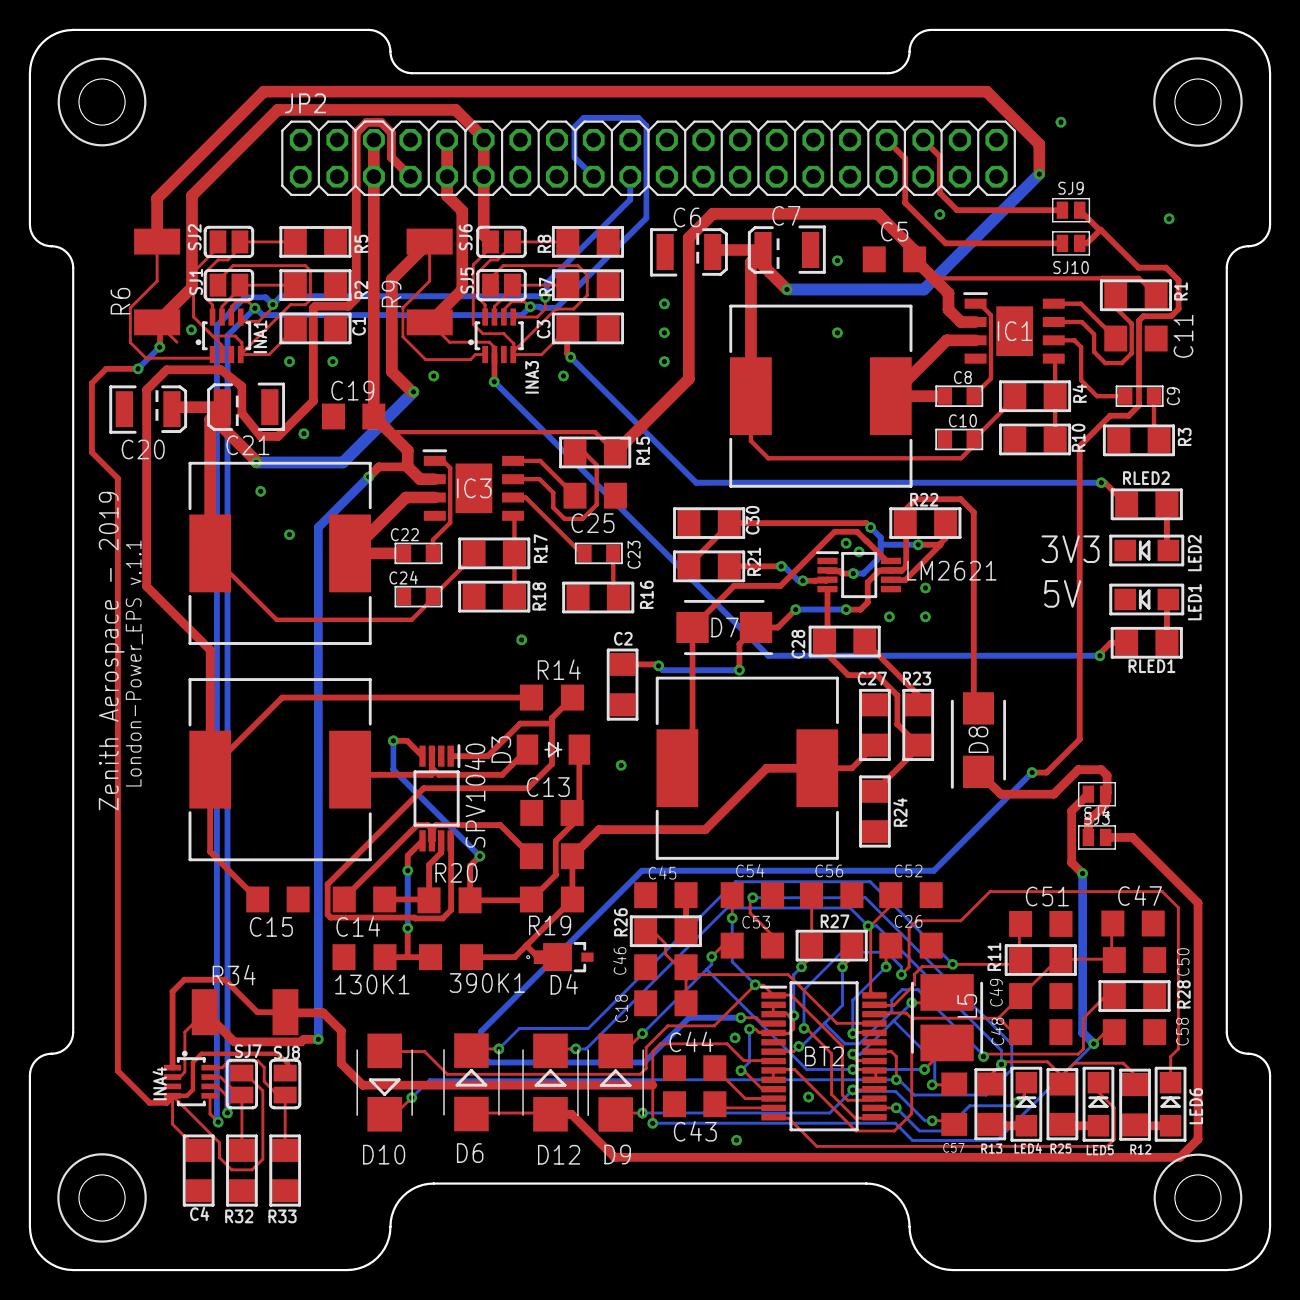
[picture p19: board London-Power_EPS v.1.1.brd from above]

Board: 2 copper layers, 86.0 x 86.0 mm, 114 parts (0 on the bottom side), 71 nets.

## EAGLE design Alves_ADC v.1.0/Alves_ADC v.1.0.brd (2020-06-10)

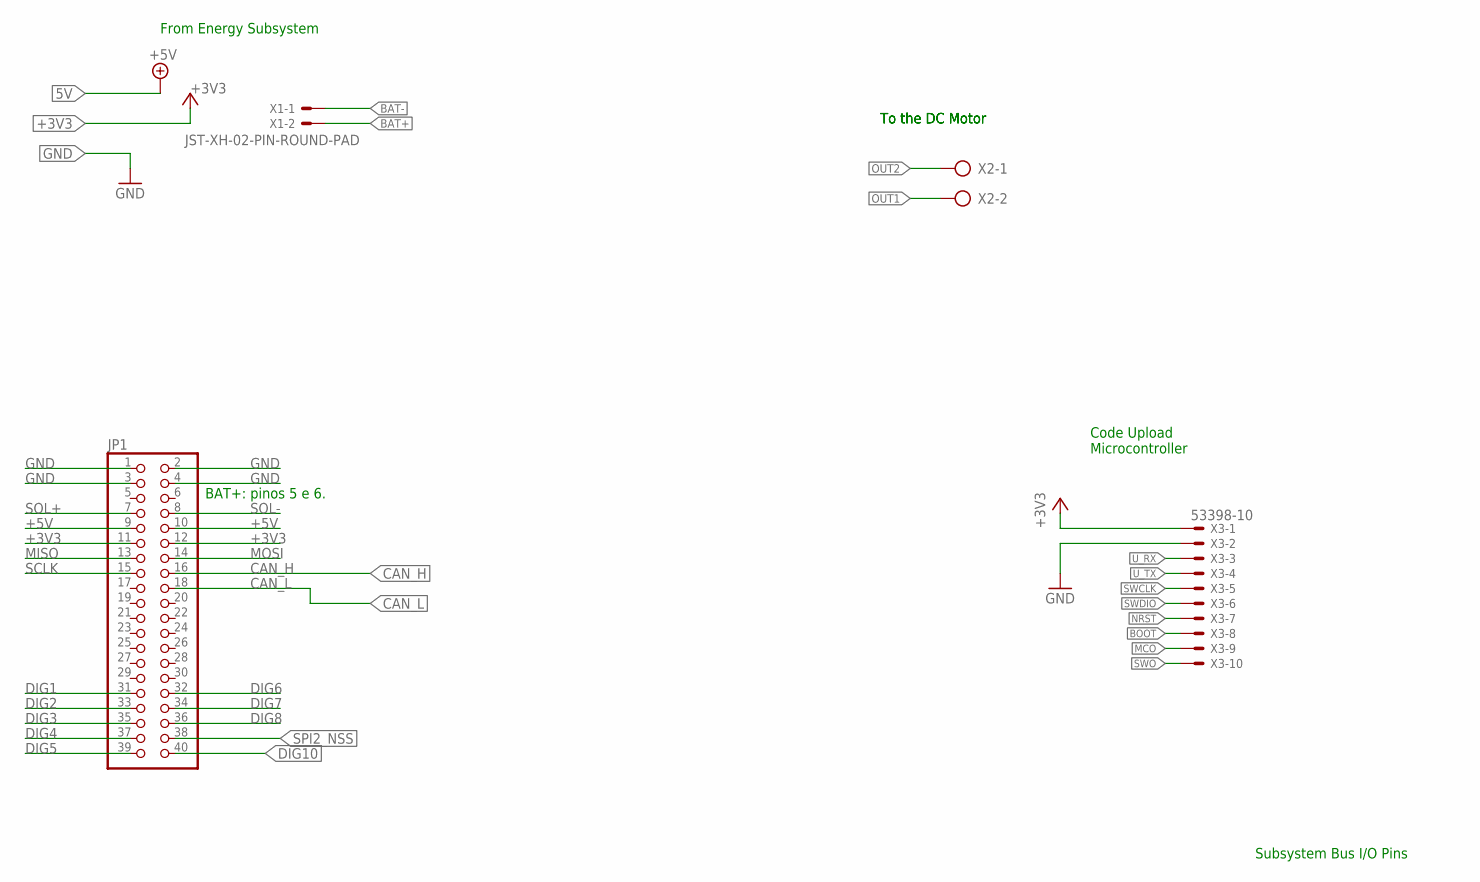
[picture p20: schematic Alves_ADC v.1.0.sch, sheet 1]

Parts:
JP1: PINHD-2X20; 2X20
X1: JST-XH-02-PIN-ROUND-PAD; JST-XH-02-PACKAGE-ROUND-PAD
X2: AK500/2
X3: 53398-10

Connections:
+3V3: JP1.11, JP1.12, X3.1; also elsewhere on the board
+5V: JP1.9, JP1.10; also elsewhere on the board
BAT+: X1.2; also elsewhere on the board
BAT-: X1.1; also elsewhere on the board
BOOT: X3.8; also elsewhere on the board
CAN_H: JP1.16; also elsewhere on the board
CAN_L: JP1.18; also elsewhere on the board
DIG1: JP1.31
DIG2: JP1.33
DIG3: JP1.35
DIG4: JP1.37
DIG5: JP1.39
DIG6: JP1.32
DIG7: JP1.34
DIG8: JP1.36
DIG10: JP1.40; also elsewhere on the board
GND: JP1.1, JP1.2, JP1.3, JP1.4, X3.2; also elsewhere on the board
MCO: X3.9; also elsewhere on the board
MISO: JP1.13; also elsewhere on the board
MOSI: JP1.14; also elsewhere on the board
NRST: X3.7; also elsewhere on the board
OUT1: X2.2; also elsewhere on the board
OUT2: X2.1; also elsewhere on the board
SCLK: JP1.15; also elsewhere on the board
SOL+: JP1.7
SOL-: JP1.8
SPI2_NSS: JP1.38; also elsewhere on the board
SWCLK: X3.5; also elsewhere on the board
SWDIO: X3.6; also elsewhere on the board
SWO: X3.10; also elsewhere on the board
U_RX: X3.3; also elsewhere on the board
U_TX: X3.4; also elsewhere on the board

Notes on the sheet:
Subsystem Bus I/O Pins
From Energy Subsystem
To the DC Motor
Code Upload Microcontroller
BAT+: pinos 5 e 6.

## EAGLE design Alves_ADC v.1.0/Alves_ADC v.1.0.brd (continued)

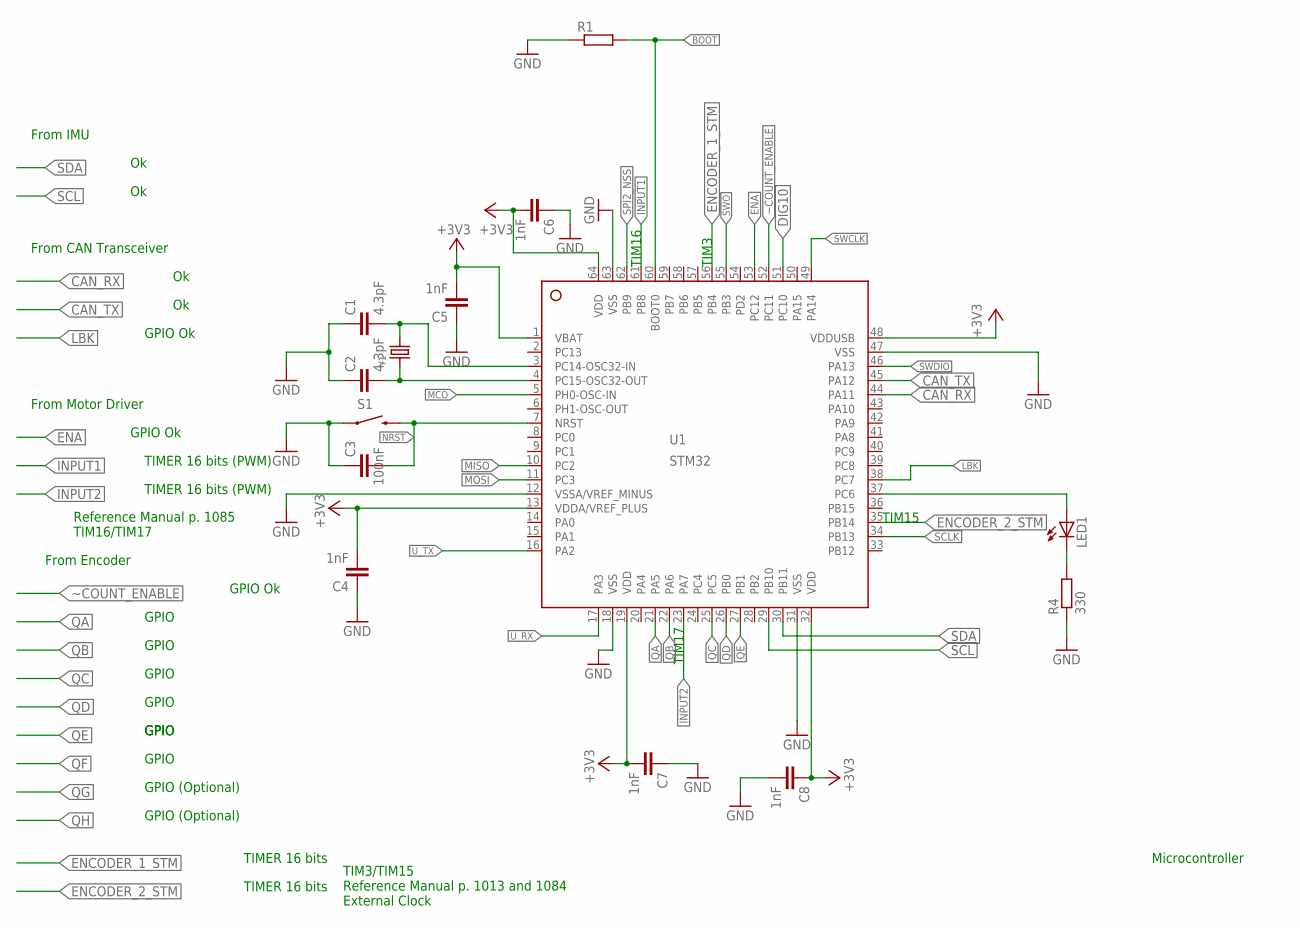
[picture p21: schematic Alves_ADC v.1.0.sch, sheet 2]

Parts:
C1, C2: 4.3pF; C1206
C3: 100nF; C1206
C4, C5, C6, C7, C8: 1nF; C1206
LED1: LEDSMT1206; 1206
R1: R-EU_R1206; R1206
R4: 330; R1206
S1: SWITCH-MOMENTARY-2SMD-1101NE; TACTILE-SWITCH-1101NE
U1: STM32; LQFP64_10X10
Y1: CRYSTAL8X3.8SMT; CRYSTAL_8X3.8

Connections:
+3V3: C4.2, C5.2, C6.2, C7.2, C8.1, U1.1 (VBAT), U1.13 (VDDA/VREF_PLUS), U1.19 (VDD), U1.32 (VDD), U1.48 (VDDUSB), U1.64 (VDD); also elsewhere on the board
BOOT: R1.2, U1.60 (BOOT0); also elsewhere on the board
CAN_RX: U1.44 (PA11); also elsewhere on the board
CAN_TX: U1.45 (PA12); also elsewhere on the board
DIG10: U1.51 (PC10); also elsewhere on the board
ENA: U1.53 (PC12); also elsewhere on the board
ENCODER_1_STM: U1.56 (PB4); also elsewhere on the board
ENCODER_2_STM: U1.35 (PB14); also elsewhere on the board
GND: C1.1, C2.1, C3.1, C4.1, C5.1, C6.1, C7.1, C8.2, R1.1, R4.1, S1.1, U1.12 (VSSA/VREF_MINUS), U1.18 (VSS), U1.31 (VSS), U1.47 (VSS), U1.63 (VSS); also elsewhere on the board
INPUT1: U1.61 (PB8); also elsewhere on the board
INPUT2: U1.23 (PA7); also elsewhere on the board
LBK: U1.38 (PC7); also elsewhere on the board
MCO: U1.5 (PH0-OSC-IN); also elsewhere on the board
MISO: U1.10 (PC2); also elsewhere on the board
MOSI: U1.11 (PC3); also elsewhere on the board
unnamed: LED1.A, U1.37 (PC6)
unnamed: C1.2, U1.3 (PC14-OSC32-IN), Y1.P$4 (2)
unnamed: C2.2, U1.4 (PC15-OSC32-OUT), Y1.P$1 (1)
unnamed: LED1.C, R4.2
NRST: C3.2, S1.2, U1.7 (NRST); also elsewhere on the board
QA: U1.21 (PA5); also elsewhere on the board
QB: U1.22 (PA6); also elsewhere on the board
QC: U1.25 (PC5); also elsewhere on the board
QD: U1.26 (PB0); also elsewhere on the board
QE: U1.27 (PB1); also elsewhere on the board
SCL: U1.29 (PB10); also elsewhere on the board
SCLK: U1.34 (PB13); also elsewhere on the board
SDA: U1.30 (PB11); also elsewhere on the board
SPI2_NSS: U1.62 (PB9); also elsewhere on the board
SWCLK: U1.49 (PA14); also elsewhere on the board
SWDIO: U1.46 (PA13); also elsewhere on the board
SWO: U1.55 (PB3); also elsewhere on the board
U_RX: U1.17 (PA3); also elsewhere on the board
U_TX: U1.16 (PA2); also elsewhere on the board
~COUNT_ENABLE: U1.52 (PC11); also elsewhere on the board

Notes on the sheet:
Microcontroller
From IMU
From Motor Driver
From CAN Transceiver
From Encoder
GPIO Ok
TIMER 16 bits (PWM)
TIMER 16 bits
GPIO (Optional)
Reference Manual p. 1085 TIM16/TIM17
TIM3/TIM15 Reference Manual p. 1013 and 1084 External Clock
TIM15
TIM17
TIM16
TIM3
GPIO

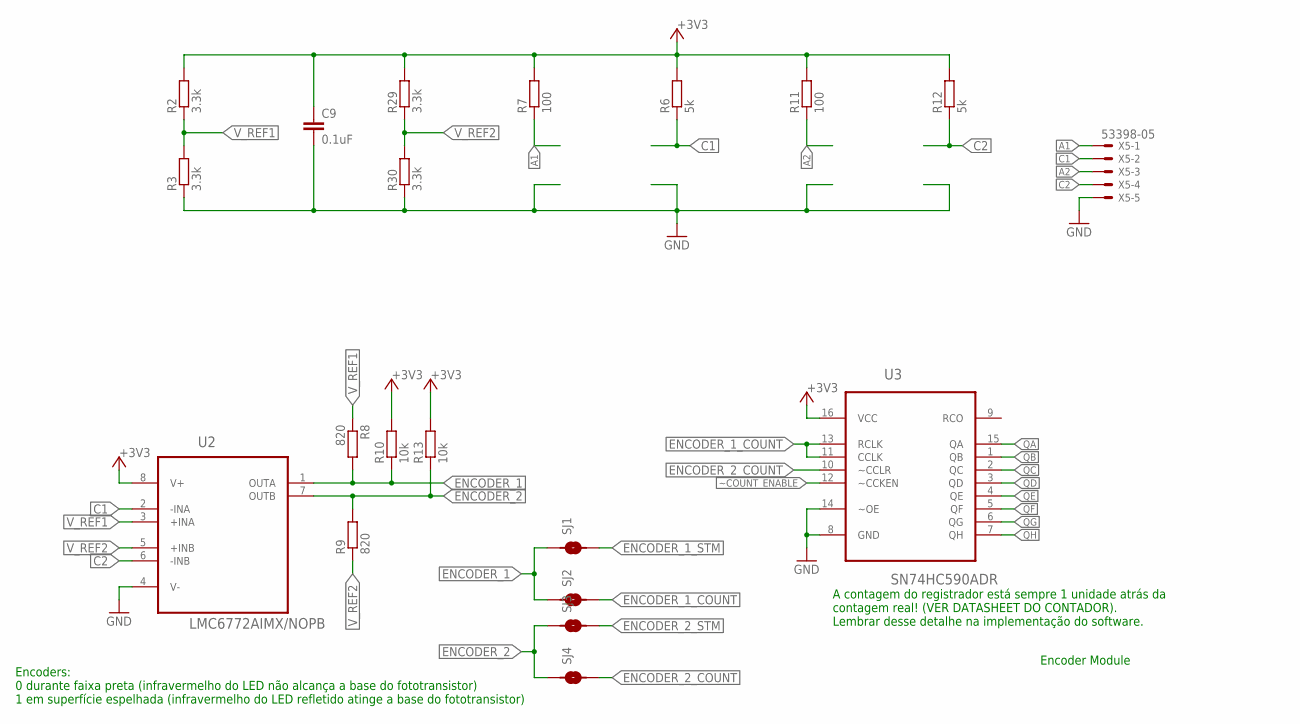
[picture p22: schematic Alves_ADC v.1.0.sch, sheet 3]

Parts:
C9: 0.1uF; C1206
R2, R3, R29, R30: 3.3k; R1206
R6, R12: 5k; R1206
R7, R11: 100; R1206
R8, R9: 820; R1206
R10, R13: 10k; R1206
SJ1, SJ2, SJ3, SJ4: SMD-JUMPER-2
U2: LMC6772AIMX/NOPB; SOIC127P600X175-8N
U3: SN74HC590ADR; SOIC127P600X175-16N
X5: 53398-05

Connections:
+3V3: C9.1, R2.2, R6.2, R7.2, R10.2, R11.2, R12.2, R13.2, R29.2, U2.8 (V+), U3.16 (VCC); also elsewhere on the board
A1: R7.1, X5.1
A2: R11.1, X5.3
C1: R6.1, U2.2 (-INA), X5.2
C2: R12.1, U2.6 (-INB), X5.4
ENCODER_1: R8.2, R10.1, SJ1.1, SJ2.1, U2.1 (OUTA)
ENCODER_1_COUNT: SJ2.2, U3.11 (CCLK), U3.13 (RCLK)
ENCODER_1_STM: SJ1.2; also elsewhere on the board
ENCODER_2: R9.2, R13.1, SJ3.1, SJ4.1, U2.7 (OUTB)
ENCODER_2_COUNT: SJ4.2, U3.10 (~CCLR)
ENCODER_2_STM: SJ3.2; also elsewhere on the board
GND: C9.2, R3.1, R30.1, U2.4 (V-), U3.8 (GND), U3.14 (~OE), X5.5; also elsewhere on the board
QA: U3.15 (QA); also elsewhere on the board
QB: U3.1 (QB); also elsewhere on the board
QC: U3.2 (QC); also elsewhere on the board
QD: U3.3 (QD); also elsewhere on the board
QE: U3.4 (QE); also elsewhere on the board
QF: U3.5 (QF)
QG: U3.6 (QG)
QH: U3.7 (QH)
V_REF1: R2.1, R3.2, R8.1, U2.3 (+INA)
V_REF2: R9.1, R29.1, R30.2, U2.5 (+INB)
~COUNT_ENABLE: U3.12 (~CCKEN); also elsewhere on the board

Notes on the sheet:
Encoder Module
Encoders: 0 durante faixa preta (infravermelho do LED não alcança a base do fototransistor) 1 em superfície espelhada (infravermelho do LED refletido atinge a base do fototransistor)
A contagem do registrador está sempre 1 unidade atrás da contagem real! (VER DATASHEET DO CONTADOR). Lembrar desse detalhe na implementação do software.

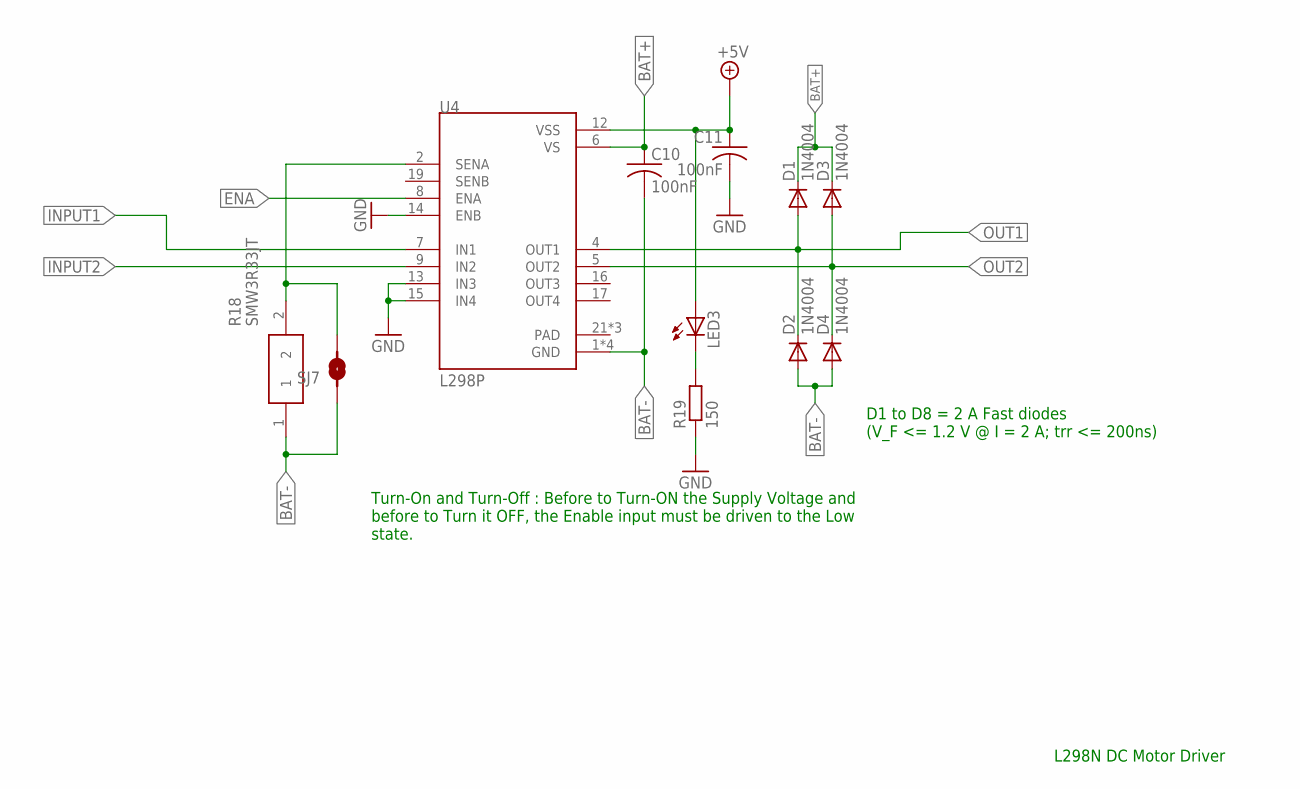
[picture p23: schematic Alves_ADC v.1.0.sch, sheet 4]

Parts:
C10, C11: 100nF; C050-024X044
D1, D2, D3, D4: 1N4004; DO41-10
LED3: LEDSMT1206; 1206
R18: SMW3R33JT; RESM12055X530N
R19: 150; R1206
SJ7: SMD-JUMPER-2
U4: L298P; SOIC127P1420X360-20N

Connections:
+5V: C11.1, LED3.A, U4.12 (VSS); also elsewhere on the board
BAT+: C10.1, D1.C, D3.C, U4.6 (VS); also elsewhere on the board
BAT-: C10.2, D2.A, D4.A, R18.1, SJ7.1, U4.1 (GND), U4.10 (GND), U4.11 (GND), U4.20 (GND); also elsewhere on the board
ENA: U4.8 (ENA); also elsewhere on the board
GND: C11.2, R19.1, U4.13 (IN3), U4.14 (ENB), U4.15 (IN4); also elsewhere on the board
INPUT1: U4.7 (IN1); also elsewhere on the board
INPUT2: U4.9 (IN2); also elsewhere on the board
unnamed: LED3.C, R19.2
unnamed: R18.2, SJ7.2, U4.2 (SENA)
OUT1: D1.A, D2.C, U4.4 (OUT1); also elsewhere on the board
OUT2: D3.A, D4.C, U4.5 (OUT2); also elsewhere on the board

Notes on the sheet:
L298N DC Motor Driver
D1 to D8 = 2 A Fast diodes (V_F <= 1.2 V @ I = 2 A; trr <= 200ns)
Turn-On and Turn-Off : Before to Turn-ON the Supply Voltage and before to Turn it OFF, the Enable input must be driven to the Low state.

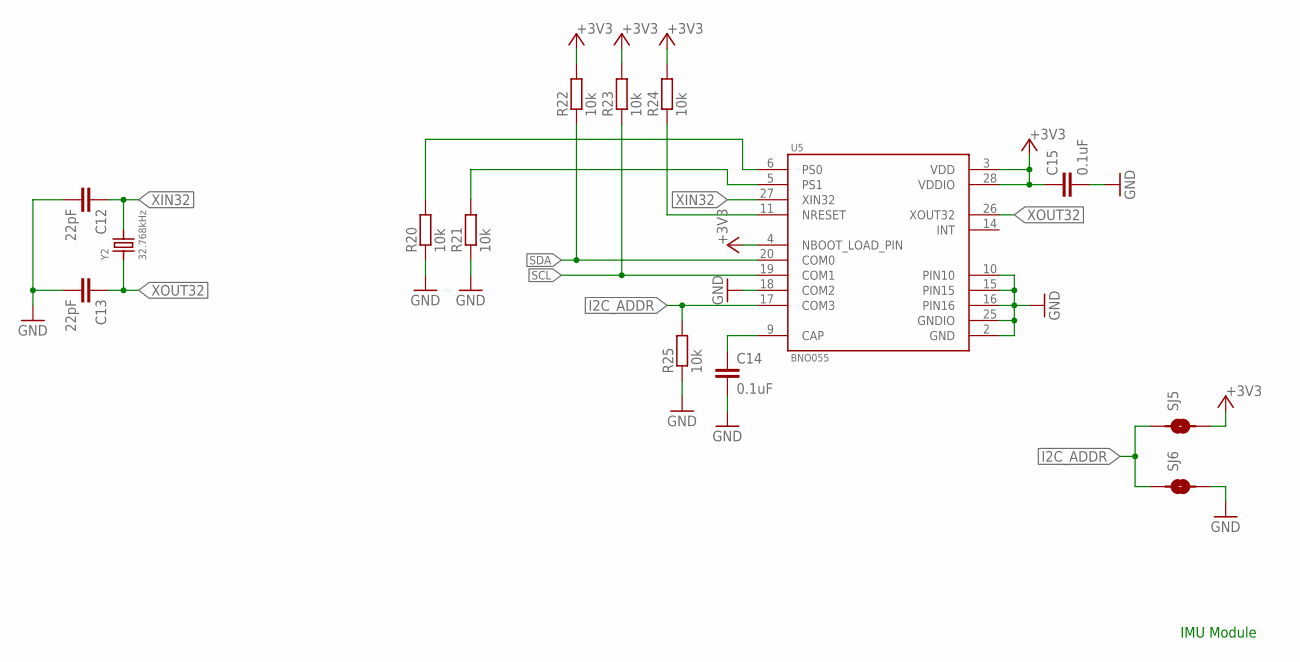
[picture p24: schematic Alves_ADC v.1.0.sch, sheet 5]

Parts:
C12, C13: 22pF; C1206
C14, C15: 0.1uF; C1206
R20, R21, R22, R23, R24, R25: 10k; R1206
SJ5, SJ6: SMD-JUMPER-2
U5: BNO055; LGA28R50P4X10_380X520X100
Y2: 32.768kHz; CRYSTAL_8X3.8

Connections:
+3V3: C15.1, R22.2, R23.2, R24.2, SJ5.2, U5.3 (VDD), U5.4 (NBOOT_LOAD_PIN), U5.28 (VDDIO); also elsewhere on the board
GND: C12.2, C13.2, C14.2, C15.2, R20.1, R21.1, R25.1, SJ6.2, U5.2 (GND), U5.10 (PIN10), U5.15 (PIN15), U5.16 (PIN16), U5.18 (COM2), U5.25 (GNDIO); also elsewhere on the board
I2C_ADDR: R25.2, SJ5.1, SJ6.1, U5.17 (COM3)
unnamed: C14.1, U5.9 (CAP)
NRESET: R24.1, U5.11 (NRESET)
PS0: R20.2, U5.6 (PS0)
PS1: R21.2, U5.5 (PS1)
SCL: R23.1, U5.19 (COM1); also elsewhere on the board
SDA: R22.1, U5.20 (COM0); also elsewhere on the board
XIN32: C12.1, U5.27 (XIN32), Y2.P$4 (2)
XOUT32: C13.1, U5.26 (XOUT32), Y2.P$1 (1)

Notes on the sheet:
IMU Module

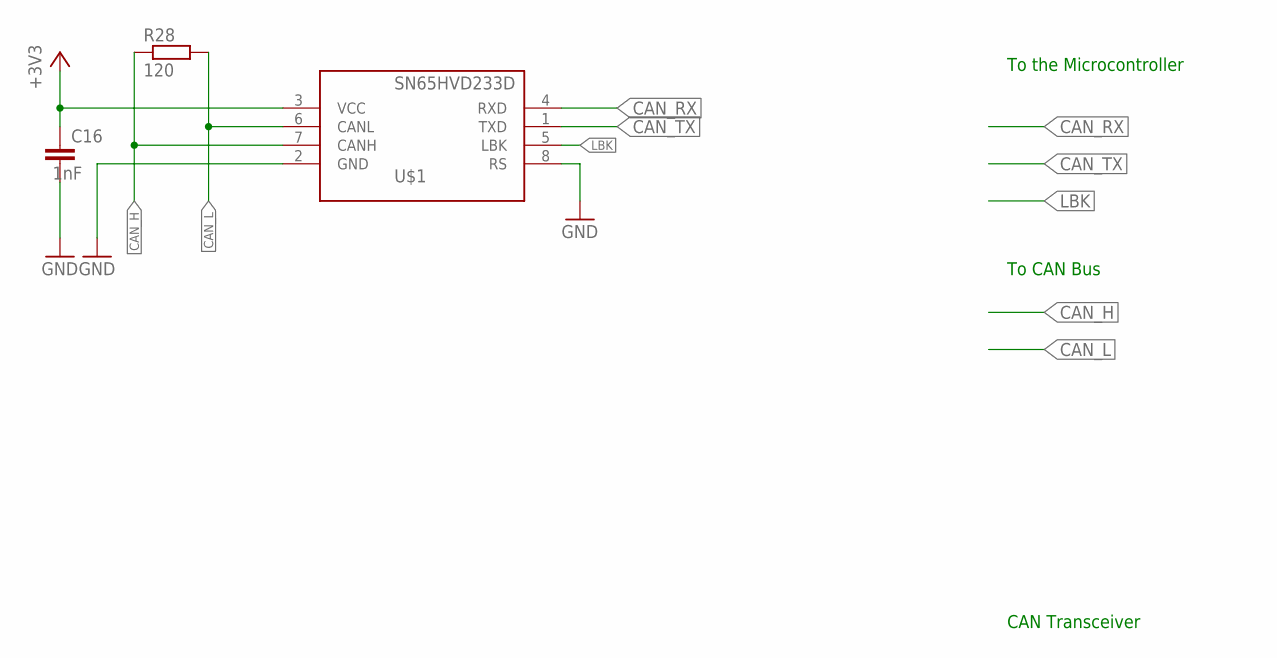
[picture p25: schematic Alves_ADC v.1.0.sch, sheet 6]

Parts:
C16: 1nF; C1206
R28: 120; R1206
U$1: SN65HVD233D; SOIC8

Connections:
+3V3: C16.1, U$1.3 (VCC); also elsewhere on the board
CAN_H: R28.1, U$1.7 (CANH); also elsewhere on the board
CAN_L: R28.2, U$1.6 (CANL); also elsewhere on the board
CAN_RX: U$1.4 (RXD); also elsewhere on the board
CAN_TX: U$1.1 (TXD); also elsewhere on the board
GND: C16.2, U$1.2 (GND), U$1.8 (RS); also elsewhere on the board
LBK: U$1.5 (LBK); also elsewhere on the board

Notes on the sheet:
CAN Transceiver
To the Microcontroller
To CAN Bus



Board: 2 copper layers, 86.0 x 86.0 mm, 66 parts (28 on the bottom side), 61 nets.

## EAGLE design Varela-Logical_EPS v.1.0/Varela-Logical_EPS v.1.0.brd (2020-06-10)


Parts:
C1, C3, C4, C6, C9: 0.1µF; 1206
C2, C5: 4.3pF; C1206
C7: 100nF; C1206
C8, C10, C11, C12, C13, C14: 1nF; C1206
CAN1: SN65HVD233D; SOIC8
D1, D2, D3, D4: DIODE-DO-214AC; DO-214AC
INA1, INA3, INA4, INA6, INA9: INA219BIDCNT; SOT23-8
JP2: PINHD-2X20; 2X20
LED1: LEDSMT1206; 1206
R1, R3, R4: 100; R1206
R2, R5, R7, R8, R10, R11, R16, R17, R25, R26: 10K; 1206
R6, R9, R12, R18, R27: 0.1; R2512
R14: 100k; R1206
R15: 120; R1206
R19, R20, R21, R22: 4.7k; R1206
R23: R-EU_R1206; R1206
R28: 68; R1206
S1: SWITCH-MOMENTARY-2SMD-1101NE; TACTILE-SWITCH-1101NE
SJ1, SJ2, SJ6, SJ7, SJ8, SJ9, SJ11, SJ12, SJ17, SJ18: SOLDERJUMPERREFLOW_NOPASTE; SOLDERJUMPER_REFLOW_NOPASTE
SJ3: SMD-JUMPER-2
T1: TIP122; TO220
U1: STM32; LQFP64_10X10
X1, X2, X3, X4: 53398-02
X7: 53398-10
X8: JST-XH-03-PIN-ROUND-PAD; JST-XH-03-PACKAGE-ROUND-PAD
X9: 53261-04
Y1: 32.768kHz; CRYSTAL_8X3.8

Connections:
5V: JP2.9, JP2.10
+3V3: C1.1, C3.1, C4.1, C6.1, C8.2, C9.1, C10.2, C11.2, C12.1, C13.2, C14.1, CAN1.3 (VCC), INA1.4 (VCC), INA3.4 (VCC), INA4.4 (VCC), INA6.4 (VCC), INA9.4 (VCC), JP2.11, JP2.12, R1.2, R3.2, R4.2, R19.2, R20.2, R21.1, R22.1, SJ1.1, SJ2.1, SJ6.1, SJ7.1, SJ8.1, SJ9.1, SJ11.1, SJ12.1, SJ17.1, SJ18.1, U1.1 (VBAT), U1.13 (VDDA/VREF_PLUS), U1.19 (VDD), U1.32 (VDD), U1.48 (VDDUSB), U1.64 (VDD), X7.1
BAT+: INA3.2 (VIN-), JP2.5, JP2.6, R9.1, X8.1
BAT_OUT: INA3.1 (VIN+), R9.2
BOOT: R14.2, U1.60 (BOOT0), X7.8
CAN1_RX: CAN1.4 (RXD), U1.44 (PA11)
CAN1_TX: CAN1.1 (TXD), U1.45 (PA12)
CAN_H: CAN1.7 (CANH), JP2.16, R15.1
CAN_L: CAN1.6 (CANL), JP2.18, R15.2
CS_1: JP2.31, U1.20 (PA4)
DIG2: JP2.33, U1.40 (PC9)
DIG3: JP2.35, X9.4
DIG4: JP2.37
DIG5: JP2.39
DIG6: JP2.32
DIG7: JP2.34
DIG8: JP2.36
DIG9: JP2.38
DIG10: JP2.40
GND: C1.2, C2.1, C3.2, C4.2, C5.1, C6.2, C7.1, C8.1, C9.2, C10.1, C11.1, C12.2, C13.1, C14.2, CAN1.2 (GND), CAN1.8 (RS), INA1.3 (GND), INA3.3 (GND), INA4.3 (GND), INA6.3 (GND), INA9.3 (GND), JP2.1, JP2.2, JP2.3, JP2.4, R2.1, R5.1, R7.1, R8.1, R10.1, R11.1, R14.1, R16.1, R17.1, R25.1, R26.1, R28.1, S1.1, SJ3.2, T1.3 (E), U1.12 (VSSA/VREF_MINUS), U1.18 (VSS), U1.31 (VSS), U1.47 (VSS), U1.63 (VSS), X7.2, X8.3
LBK: CAN1.5 (LBK), U1.38 (PC7)
MCO: U1.5 (PH0-OSC-IN), X7.9
MISO_1: JP2.13, U1.22 (PA6)
MOSI_1: JP2.14, U1.23 (PA7)
unnamed: C2.2, U1.3 (PC14-OSC32-IN), Y1.P$4 (2)
unnamed: R23.1, T1.1 (B)
unnamed: C5.2, U1.4 (PC15-OSC32-OUT), Y1.P$1 (1)
unnamed: INA1.8 (A1), R5.2, SJ2.2
unnamed: INA1.7 (A0), R2.2, SJ1.2
unnamed: INA3.8 (A1), R8.2, SJ9.2
unnamed: INA3.7 (A0), R7.2, SJ6.2
unnamed: INA4.8 (A1), R11.2, SJ8.2
unnamed: INA4.7 (A0), R10.2, SJ7.2
unnamed: LED1.A, U1.37 (PC6)
unnamed: LED1.C, R28.2
unnamed: INA6.8 (A1), R17.2, SJ12.2
unnamed: INA6.7 (A0), R16.2, SJ11.2
unnamed: INA9.8 (A1), R26.2, SJ18.2
unnamed: INA9.7 (A0), R25.2, SJ17.2
NRST: C7.2, S1.2, U1.7 (NRST), X7.7
PAINEL1_OUT: INA1.1 (VIN+), R6.2, X1.1
PAINEL1_TO_DIODE: D1.A, INA1.2 (VIN-), R6.1
PAINEL2_OUT: INA4.1 (VIN+), R12.2, X2.1
PAINEL2_TO_DIODE: D2.A, INA4.2 (VIN-), R12.1
PAINEL3_OUT: INA6.1 (VIN+), R18.2, X3.1
PAINEL3_TO_DIODE: D3.A, INA6.2 (VIN-), R18.1
PAINEL4_OUT: INA9.1 (VIN+), R27.2, X4.1
PAINEL4_TO_DIODE: D4.A, INA9.2 (VIN-), R27.1
PWM_T: R23.2, U1.14 (PA0)
RES-: T1.2 (C), X8.2
SCLK_1: JP2.15, U1.21 (PA5)
SCL_1: INA3.5 (SCL), JP2.19, R22.2, U1.58 (PB6)
SCL_2: INA1.5 (SCL), INA4.5 (SCL), INA6.5 (SCL), INA9.5 (SCL), R20.1, U1.34 (PB13)
SDA_1: INA3.6 (SDA), JP2.17, R21.2, U1.59 (PB7)
SDA_2: INA1.6 (SDA), INA4.6 (SDA), INA6.6 (SDA), INA9.6 (SDA), R19.1, U1.35 (PB14)
SOL+: D1.C, D2.C, D3.C, D4.C, JP2.7
SOL-: JP2.8, SJ3.1, X1.2, X2.2, X3.2, X4.2
SWCLK: U1.49 (PA14), X7.5
SWDIO: U1.46 (PA13), X7.6
SWO: U1.55 (PB3), X7.10
THERM1: R1.1, U1.9 (PC1), X9.1
THERM2: R3.1, U1.15 (PA1), X9.2
THERM3: R4.1, U1.24 (PC4), X9.3
U_RX: U1.17 (PA3), X7.3
U_TX: U1.16 (PA2), X7.4

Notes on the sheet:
ENTRADA PAINÉIS
BARRAMENTO
CORRENTE ENTRADA PAINÉIS
CORRENTE SAÍDA BATERIA
Painel 1
Painel 2
Painel 3
Painel 4
DIODOS PAINÉIS SOLARES
CONECTOR PACK BATERIAS
Sinal Thermistor
Potência (Bateria/Aquecedor)
RESISTORES DOS THERMISTORES
CONTROLE TEMPERATURA
Author: Leonardo Baptistella
Zenith Aerospace
MICROCONTROLADOR
MICROCONTROLADOR CODE UPLOAD
CAN TRANSCEIVER


Board: 2 copper layers, 86.0 x 86.0 mm, 74 parts (0 on the bottom side), 58 nets.

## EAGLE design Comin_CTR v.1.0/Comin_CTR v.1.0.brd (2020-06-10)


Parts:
JP2: PINHD-2X20; 2X20
SJ1, SJ2, SJ3, SJ4, SJ5, SJ6, SJ7, SJ8, SJ9, SJ10, SJ11, SJ12: SJ
U$1, U$2: RASPBERRY-PI+PIZERO; RASPBERRY-PI-ZERO

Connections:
3V3: JP2.11, JP2.12
5V: JP2.9, JP2.10, U$1.2 (2-5V), U$1.4 (4-5V), U$2.2 (2-5V), U$2.4 (4-5V)
COM1: U$1.22 (22-GPIO25), U$2.22 (22-GPIO25)
COM2: U$1.24 (24-GPIO8), U$2.24 (24-GPIO8)
COM3: U$1.26 (26-GPIO7), U$2.26 (26-GPIO7)
COM4: U$1.32 (32-GPIO12), U$2.32 (32-GPIO12)
CS_CAURIN: JP2.27
GND: JP2.1, JP2.2, JP2.3, JP2.4, U$1.6 (6-GND), U$1.9 (9-GND), U$1.14 (14-GND), U$1.20 (20-GND), U$1.25 (25-GND), U$1.30 (30-GND), U$1.34 (34-GND), U$1.39 (39-GND), U$2.6 (6-GND), U$2.9 (9-GND), U$2.14 (14-GND), U$2.20 (20-GND), U$2.25 (25-GND), U$2.30 (30-GND), U$2.34 (34-GND), U$2.39 (39-GND)
GP1: JP2.31, SJ6.1
GP2: JP2.33, SJ7.1
GP3: JP2.35, SJ8.1
GP4: JP2.37, SJ9.1
GP5: JP2.39, SJ10.1
GP6: JP2.32, SJ5.2
GP7: JP2.34, SJ2.1
GP8: JP2.36, SJ1.1
GP9: JP2.38, SJ3.1
GP10: JP2.40, SJ4.1
MISO: JP2.13
MOSI: JP2.14
unnamed: SJ1.2, U$1.33 (33-GPIO13)
unnamed: SJ2.2, U$1.35 (35-GPIO19)
unnamed: SJ3.2, U$1.31 (31-GPIO6)
unnamed: SJ5.1, U$2.36 (36-GPIO16)
unnamed: SJ4.2, U$1.29 (29-GPIO5)
unnamed: SJ6.2, U$2.29 (29-GPIO5)
unnamed: SJ7.2, U$2.31 (31-GPIO6)
unnamed: SJ8.2, U$2.33 (33-GPIO13)
unnamed: SJ9.2, U$2.35 (35-GPIO19)
unnamed: SJ10.2, U$2.37 (37-GPIO26)
unnamed: SJ11.2, U$2.5 (5-SCL1/GPIO3)
unnamed: SJ12.2, U$2.3 (3-SDA1/GPIO2)
SCKL: JP2.15
SCL: JP2.19, SJ11.1
SDA: JP2.17, SJ12.1
UART_RX: JP2.23, U$2.8 (8-TX)
UART_TX: JP2.25, U$2.10 (10-RX)

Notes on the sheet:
RASP MASTER
RASP SLAVE
BARRAMENTO

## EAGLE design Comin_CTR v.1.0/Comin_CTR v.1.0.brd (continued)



Board: 2 copper layers, 86.0 x 86.0 mm, 15 parts (12 on the bottom side), 33 nets.

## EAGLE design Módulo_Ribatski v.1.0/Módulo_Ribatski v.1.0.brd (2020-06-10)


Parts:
BT1, BT2, BT3: BATTERY-18650; BATTERY_18650-HOLDER
DEPLOY_GND: PINHD-1X1-BIGPOGO; 1X1-BIGPOGO
DEPLOY_VCC: deploy; 1X1-BIGPOGO
GND: PINHD-1X2; 1X02
HEATER: PINHD-1X2; 1X02
R1: R-EU_R1206; R1206
RES_VCC: PINHD-1X1-BIGPOGO; 1X1-BIGPOGO
S1: DTS-3
T1: TIP122; TO220
THERM: HEADER-1X4; 1X04_OVAL
TR1, TR2, TR3: THERMISTOR_R-5; R-5
VCC: PINHD-1X2; 1X02

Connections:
ANTENA: R1.1, THERM.4
DEPLOY: DEPLOY_GND.P$1, T1.2 (C)
GND: BT3.GND@1 (-), GND.1, GND.2, T1.3 (E), TR1.2, TR2.2, TR3.2
unnamed: BT1.GND@1 (-), BT2.PWR@1 (+)
unnamed: BT2.GND@1 (-), BT3.PWR@1 (+)
unnamed: THERM.1, TR1.1
unnamed: THERM.2, TR3.1
unnamed: THERM.3, TR2.1
unnamed: R1.2, T1.1 (B)
unnamed: BT1.PWR@1 (+), S1.1
RES: HEATER.1, HEATER.2
VCC: DEPLOY_VCC.P$1, RES_VCC.P$1, S1.2, VCC.1, VCC.2

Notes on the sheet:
NICROME HEATER
BUS WIRES
BATTERIES
Zenith Aerospace
Author: Leonardo Baptistella
João Matheus Siqueira
Alimentação
NICROME DEPLOY



Board: 2 copper layers, 70.0 x 70.0 mm, 16 parts (2 on the bottom side), 12 nets.

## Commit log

2021-03-01 💬 - File Rebuilt | Github Action Runner : 1
2021-03-29 Add Estruturras
    [Base stl.stl, Espaçador_Base_Motor.stl, Espaçador_Meio.stl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]

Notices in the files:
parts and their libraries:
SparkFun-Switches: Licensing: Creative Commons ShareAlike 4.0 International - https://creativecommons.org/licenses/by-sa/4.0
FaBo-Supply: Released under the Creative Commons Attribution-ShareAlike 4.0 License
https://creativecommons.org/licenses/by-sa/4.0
